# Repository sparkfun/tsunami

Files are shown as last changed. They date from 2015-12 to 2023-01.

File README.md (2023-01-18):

_Note: This repository is for the Tsunami Super WAV Trigger v1.1. For v1.2, check out the [Tsunami Super WAV Trigger (Qwiic) v1.2 GitHub repository](https://github.com/sparkfun/SparkFun_Tsunami_Super_WAV_Trigger_Qwiic)._

Tsunami Super WAV Trigger
========================================

Tsunami Super WAV Trigger (https://www.sparkfun.com/products/retired/13810)

[*Tsunami Super WAV Trigger (WIG-13810)*](https://www.sparkfun.com/products/retired/13810)

Tsunami is a polyphonic Wav file player with 4 stereo (or 8 mono) outputs.  Wav files can be triggered using the 16 onboard contacts, via MIDI, or using a serial connection to a PC or other microcontroller.

Repository Contents
-------------------

* **/Documentation** - Data sheets, additional product information
* **/Hardware** - Eagle design files (.brd, .sch)
* **/Production** - Production panel files (.brd)

Documentation
--------------
* **[Hookup Guide](https://learn.sparkfun.com/tutorials/tsunami-hookup-guide)** - Basic hookup guide for Tsunami v1.1.
* **[Official User Guide](https://cdn.sparkfun.com/assets/e/9/9/8/e/Tsunami_UserGuide_20230114.pdf)** - More detailed user guide, hosted by Robertsonics.
* **[Official Downloads Page](http://robertsonics.com/downloads/)** - Download supporting files, including firmware updates and the configuration utility.
* **[SparkFun Fritzing repo](https://github.com/sparkfun/Fritzing_Parts)** - Fritzing diagrams for SparkFun products.
* **[SparkFun 3D Model repo](https://github.com/sparkfun/3D_Models)** - 3D models of SparkFun products.

Product Versions
----------------
* [WIG-13810](https://www.sparkfun.com/products/13810) - First hardware revision.

Version History
---------------
* [Initial production Release](https://github.com/sparkfun/tsunami/commit/f42b14d72773535e83374cde73f2ca3f25164abb) - V11 hardware revision.

License Information
-------------------

The hardware design of Tsunami is _**open source**_!

Please review the LICENSE.md file for license information.

If you have any questions or concerns on licensing, please contact techsupport@sparkfun.com.

Distributed as-is; no warranty is given.

- Your friends at SparkFun.

Authors
----

Jamie Robertson @ Robertsonics & Byron Jacquot @ SparkFun Electronics

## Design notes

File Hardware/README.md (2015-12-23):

SparkFun <PRODUCT NAME> Design Files
=====================================

The .sch and .brd files hare are Eagle CAD schematic and PCB design files from SparkFun Electronics.
A freeware version of Eagle can be found [here](http://www.cadsoftusa.com/download-eagle/freeware/).

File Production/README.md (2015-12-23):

SparkFun <PRODUCT NAME> Production Files
=========================================

These are the production files SparkFun uses for printing PCBs.

License Information
-------------------
This product is open source! 

The hardware is released under [Creative Commons ShareAlike 4.0 International](https://creativecommons.org/licenses/by-sa/4.0/).

Please use, reuse, and modify these files as you see fit. Please maintain attribution to SparkFun Electronics and release anything derivative under the same license.

Distributed as-is; no warranty is given.

- Your friends at SparkFun.

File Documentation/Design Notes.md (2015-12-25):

###Tapestry Design Notes:

The initial Tapestry audio engine board is designed to be used for development purposes, and provides the basic components
of a high performance audio DSP/Playback engine, including an Atmel SAM S70 Arm Cortex M7 CPU, a microSD socket connected
via SDIO, a high-speed USB port and an AKM multi-channel audio codec providing 4 channels of input and 6 channels of output.
It also includes 10-pin, 0.05" pitch SWD/JTAG connector for use with the Atmel SAM ICE debugger during firmware development.

The design assumes that most user interface controls and connnectors, audio buffering and connectors, as well as any specific
external power connection and regulation will be contained on a second application specific "UI" board. In this way, the audio
engine can be repurposed for different end-user applications and requirements.

**Power**

Vin is assumed to be 5V. The design intent is that 5V can be supplied either through the UI header or from the USB
connection, or both. If both are plugged in, the external 5V Vin will be favored. If a wider input range using a barrel or
other type of power connector is required, the connector itself and any additional regulation can located on the UI board.

**microSD Socket**

The microSD card interfaces to the CPU using the 4-bit wide SDIO interface rather than SPI. The Atmel SAM 70 CPU is able
to recognize high speed cards and run the SDIO clock at 50Mhz, making the layout of the card and routing of the SDIO traces
somewhat critical. SDIO signals and traces should be treated as high frequency.

**Codec**

The codec interfaces to the CPU using the SAM S70 SAI resource in TDM mode for audio, and I2C for control. The design allows
for up to 4 audio input channels and 6 audio output channels.  A dual-row, 20-pin connector JP4 provides the ac coupled audio
input and output connections to and from the codec. Any additional audio signal conditioning / buffering, as well as the
desired audio connectors are assumed to be on the UI board.

**User and Control Interface**

All user interface/control signals, including Vin, are via a dual-row 26 pin header JP3. There are 16 GPIO, 8 of which
can also be configured as analog inputs or outputs. The intent is that alternate firmware versions can use these lines to
interface to trigger or gate inputs, and/or user interface controls such as analog pots, encoders, LEDs, etc. There are also
2 UARTs (Tx and Rx), one of which will be dedicated for MIDI (with the MIDI opto-isolator, related components and connectors
being located on the UI board.)

**Test Points**

Test points are provided for the TDM signals between the SAM S70 and codec. Test points are also provide for a subset of
the SDIO signals to facilitate timing SD card access. A single general purpose test point is also provided for use by the
firmware.

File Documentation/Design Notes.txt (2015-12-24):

Tapestry Design Notes:

The initial Tapestry audio engine board is designed to be used for development purposes, and provides the basic components
of a high performance audio DSP/Playback engine, inlcuding the Arm Cortex M7 CPU, a microSD socket connected via SDIO, a
high-speed USB port and a multi-channel audio codec providing 4 channels of input and 6 channels of output. It also includes
10-pin, 0.05 pitch SWD/JTAG connector for use with the Atmel SAM ICE debugger during firmware development.

The design assumes that most user interface controls and connnectors, audio buffering and connectors, as well as any specific
external power connection and regulation will be contained on a second application specific "UI" board. In this way, the audio
engine can be repurposed for different end-user applications and requirements.

Power

Vin is assumed to be 5V. The design intent is that 5V can be supplied either through the UI header or from the USB
connection, or both. If both are plugged in, the external 5V Vin will be favored. If a wider input range using a barrel
connector is required, the connector and additional regulation can located on the UI board.

microSD Socket

The microSD card interfaces to the CPU using the 4-bit wide SDIO interface rather than SPI. The Atmel SAM 70 CPU is able
to recognize high speed cards and run the SDIO clock at 50Mhz, making the layout of the card and routing of the SDIO traces
somewhat more critical. SDIO signals and traces should be considered high frequency.

Codec

The codec interfaces to the CPU using the SAM S70 SAI resource in TDM mode. The design allows for up to 4 audio input
channels and 6 audio output channels.  A dual-row 20-pin connector JP4 provides the ac coupled audio input and output
connections to and from the codec. Any additional audio signal conditioning / buffering as well as the desired audio
connectors is assumed to be on the UI board.

User and Control Interface

All user interface/control signals, including Vin, are via a dual-row 26 pin header JP3. There are 16 GPIO, 8 of which
can also be configured as analog inputs or outputs. The intent is that alternate firmware versions can use these lines to
interface to trigger or gate inputs, user interface controls such as analog pots, encoders, LEDs, etc. There are also 2 UARTs
(Tx and Rx), one of which will be used for MIDI (with the MIDI opto and connectors being located on the UI board.)

Test Points

Test points are provided for the TDM signals between the SAM S70 and codec. Test points are also provide for a subset of
the SDIO signals to facilitate timing SD card access. A single general purpose test point is also provided for use by the
firmware.

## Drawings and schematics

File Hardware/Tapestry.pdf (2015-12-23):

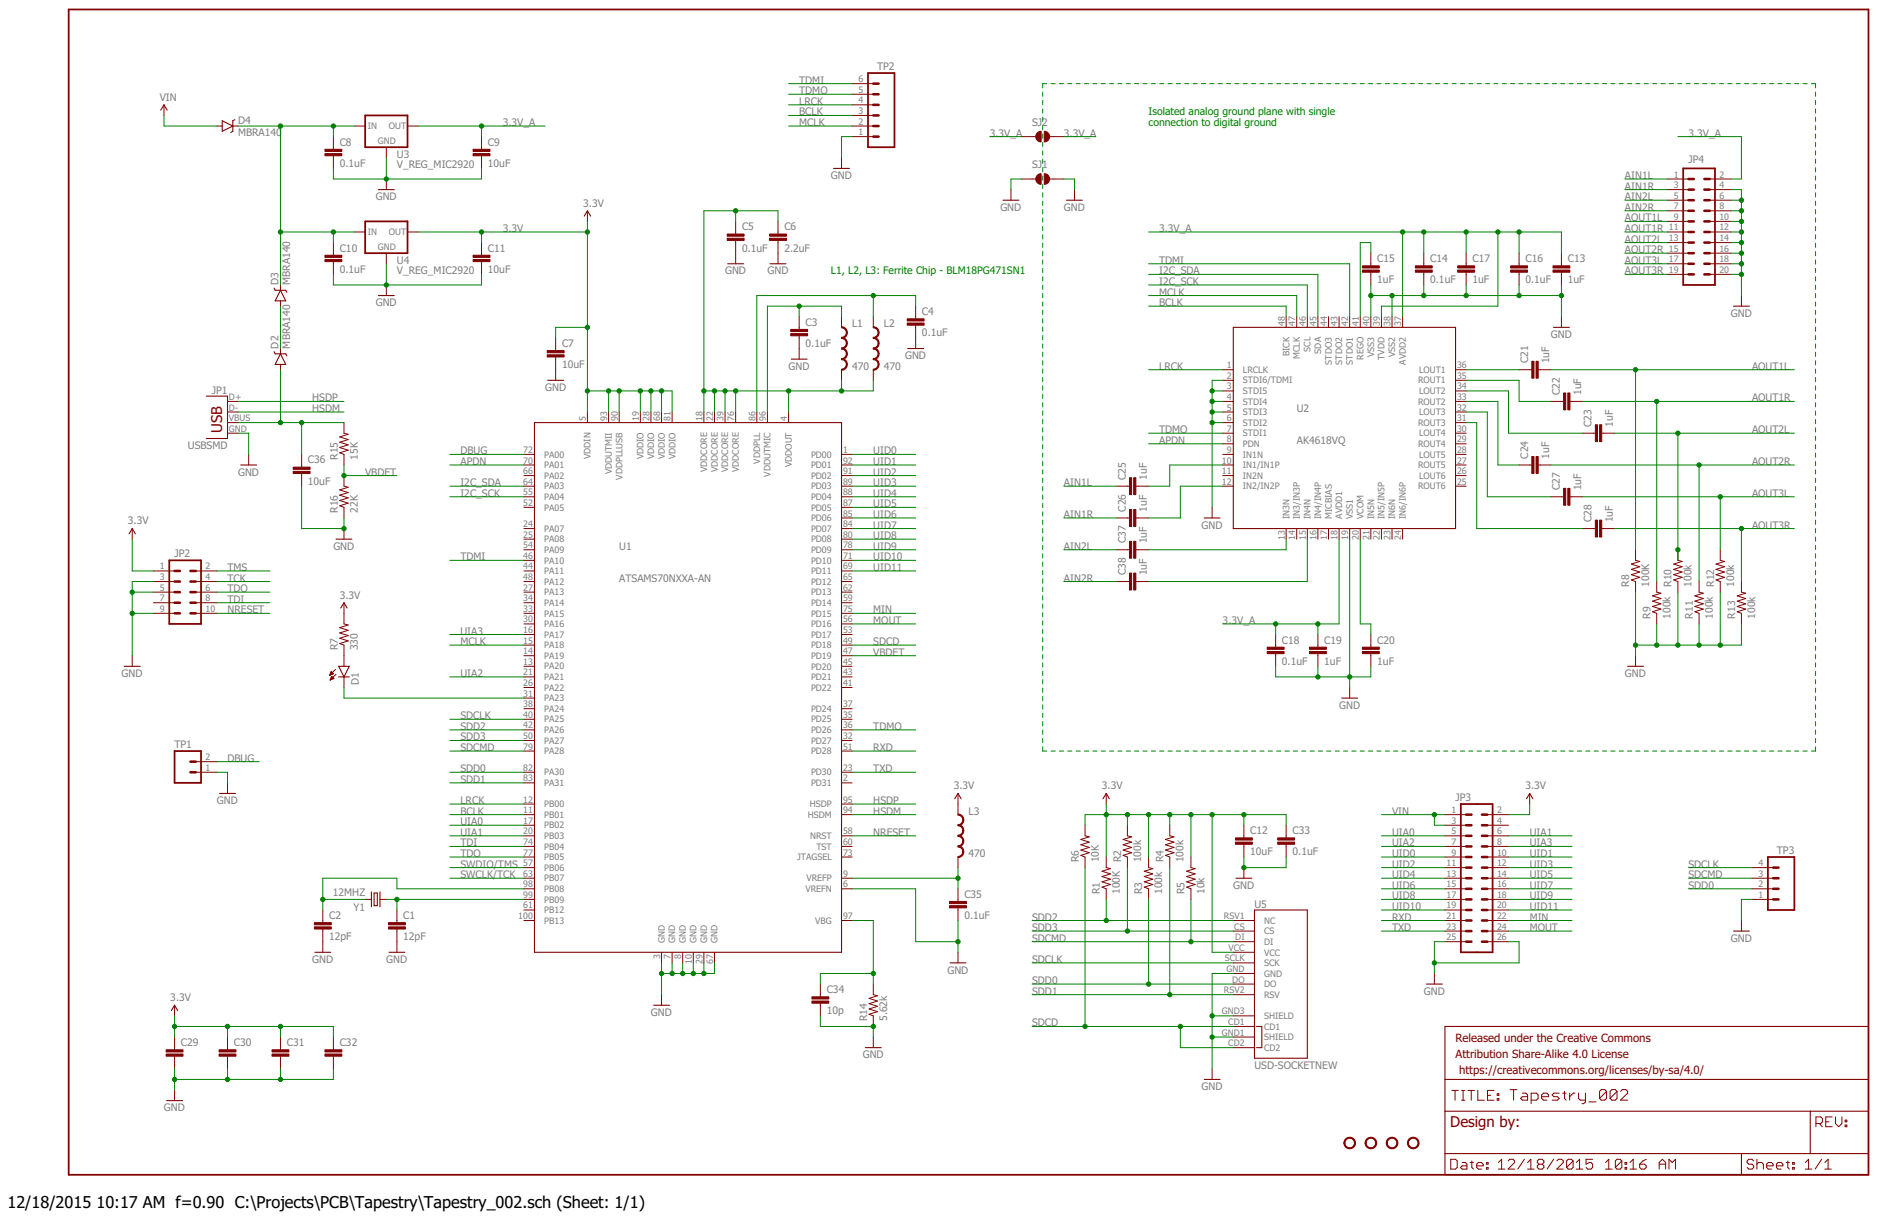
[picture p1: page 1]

Isolated analog ground plane with single
connection to digital ground

Released under the Creative Commons Attribution Share-Alike 4.0 License https://creativecommons.org/licenses/by-sa/4.0/

12/18/2015 10:17 AM f=0.90 C:\Projects\PCB\Tapestry\Tapestry_002.sch (Sheet: 1/1)

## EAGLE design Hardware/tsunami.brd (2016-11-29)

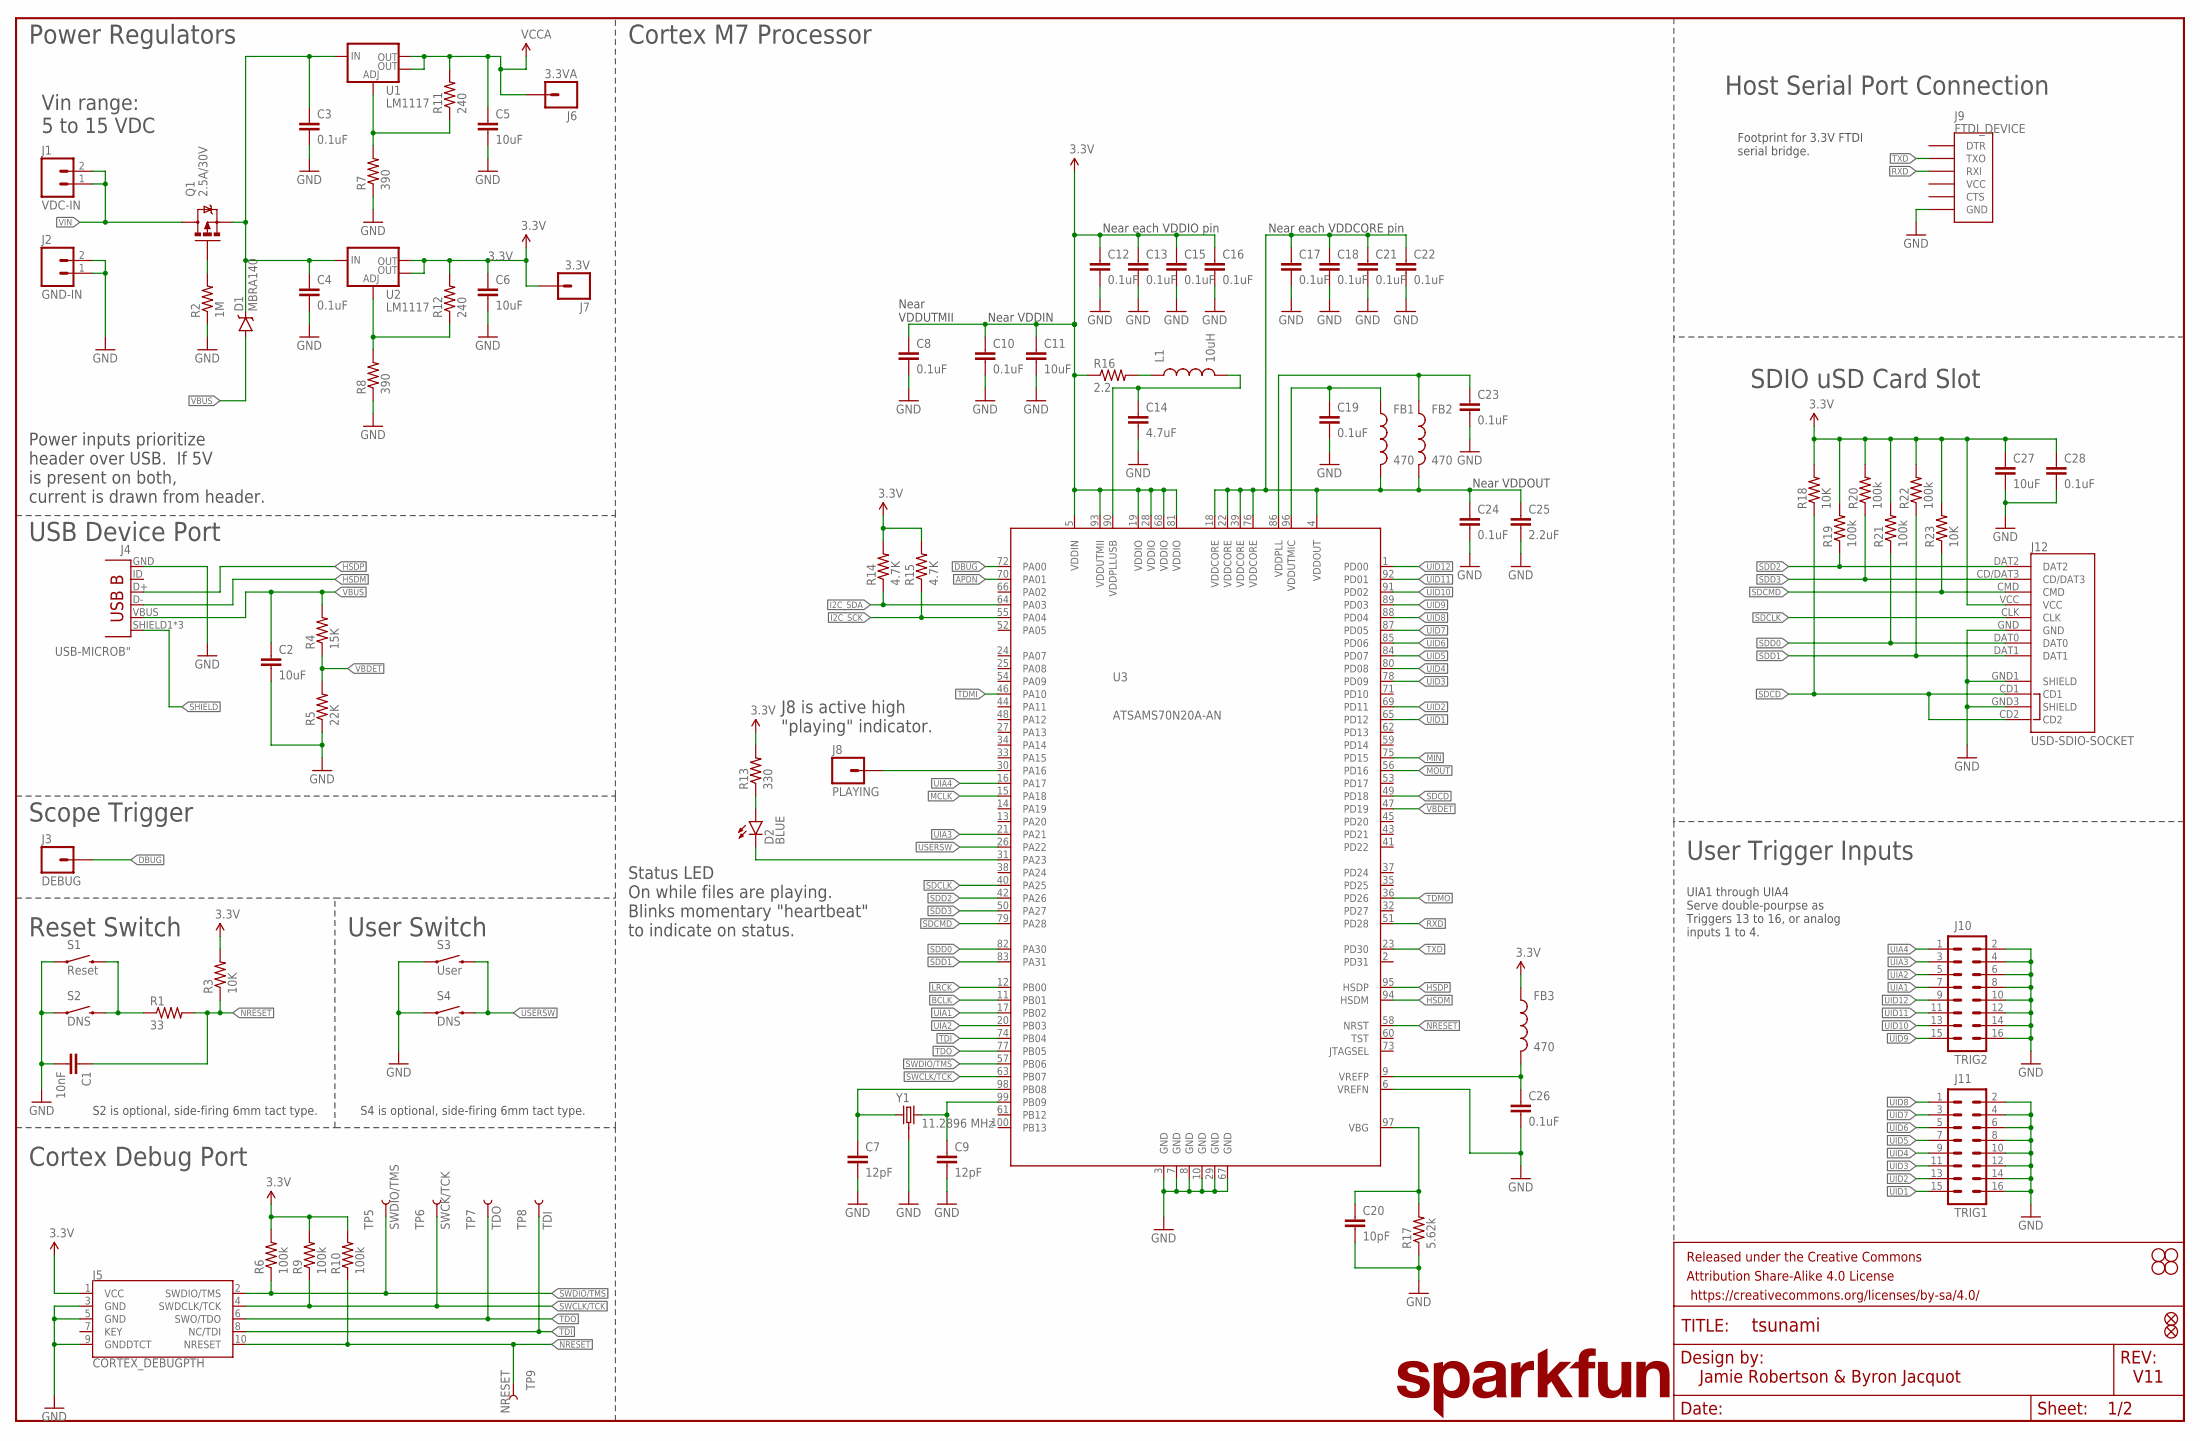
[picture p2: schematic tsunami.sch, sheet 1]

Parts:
C1: 10nF; 0603-CAP
C2, C5, C6, C11, C27: 10uF; 0603-CAP
C3, C4, C8, C10, C12, C13, C15, C16, C17, C18, C19, C21, C22, C23, C24, C26, C28: 0.1uF; 0603-CAP
C7, C9: 12pF; 0603-CAP
C14: 4.7uF; 0603-CAP
C20: 10pF; 0603-CAP
C25: 2.2uF; 0603-CAP
D1: MBRA140; SMA-DIODE
D2: BLUE; LED-0603
FB1, FB2, FB3: 470; 0603
FD1, FD2: FIDUCIALUFIDUCIAL; MICRO-FIDUCIAL
FRAME1: FRAME-LEDGER; CREATIVE_COMMONS
H1, H2, H3, H4: STAND-OFF
J1: VDC-IN; 1X02
J2: GND-IN; 1X02
J3: DEBUG; 1X01_NO_SILK
J4: USB-MICROB"; USB-B-MICRO-SMD_V03
J5: CORTEX_DEBUGPTH; 2X5-PTH-1.27MM
J6: 3.3VA; 1X01_NO_SILK
J7: 3.3V; 1X01_NO_SILK
J8: PLAYING; 1X01_NO_SILK
J9: FTDI_DEVICE; FTDI_DEVICE_SIDE
J10: TRIG2; 2X8
J11: TRIG1; 2X8
J12: USD-SDIO-SOCKET; MICRO-SD-SOCKET-SDIO
L1: 10uH; 0805
LOGO1: SFE_LOGO_NAME.2_INCH; SFE_LOGO_NAME_.2
Q1: 2.5A/30V; SOT23-3
R1: 33; 0603-RES
R2: 1M; 0603-RES
R3, R18, R23: 10K; 0603-RES
R4: 15K; 0603-RES
R5: 22K; 0603-RES
R6, R9, R10, R19, R20, R21, R22: 100k; 0603-RES
R7, R8: 390; 0603-RES
R11, R12: 240; 0603-RES
R13: 330; 0603-RES
R14, R15: 4.7K; 0603-RES
R16: 2.2; 0603-RES
R17: 5.62k; 0603-RES
S1: Reset; TACTILE-SWITCH-SMD
S2, S4: DNS; TACTILE-PTH-SIDEEZ
S3: User; TACTILE-SWITCH-SMD
TP5: SWDIO/TMS; TP_15TH
TP6: SWCK/TCK; TP_15TH
TP7: TDO; TP_15TH
TP8: TDI; TP_15TH
TP9: NRESET; TP_15TH
U1, U2: LM1117; SOT223
U3: ATSAMS70N20A-AN; LQFP100
Y1: 11.2896 MHz; CRYSTAL-OSC-SMD-5X3

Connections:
3.3V: C6.1, C8.1, C10.1, C11.1, C12.1, C13.1, C15.1, C16.1, C27.1, C28.1, FB3.1, J5.1 (VCC), J7.1, J12.VCC, R3.2, R6.2, R9.2, R10.2, R12.2, R13.2, R14.2, R15.2, R16.1, R18.2, R19.2, R20.2, R21.2, R22.2, R23.2, U2.2 (OUT), U2.4 (OUT), U3.5 (VDDIN), U3.19 (VDDIO), U3.28 (VDDIO), U3.68 (VDDIO), U3.81 (VDDIO), U3.93 (VDDUTMII); also elsewhere on the board
APDN: U3.70 (PA01); also elsewhere on the board
BCLK: U3.11 (PB01); also elsewhere on the board
DBUG: J3.1, U3.72 (PA00)
GND: C1.2, C2.2, C3.2, C4.2, C5.2, C6.2, C7.2, C8.2, C9.2, C10.2, C11.2, C12.2, C13.2, C14.2, C15.2, C16.2, C17.2, C18.2, C19.2, C20.2, C21.2, C22.2, C23.2, C24.2, C25.2, C26.2, C27.2, C28.2, J2.1, J2.2, J4.GND, J5.3 (GND), J5.5 (GND), J5.9 (GNDDTCT), J9.P$6 (GND), J10.2, J10.4, J10.6, J10.8, J10.10, J10.12, J10.14, J10.16, J11.2, J11.4, J11.6, J11.8, J11.10, J11.12, J11.14, J11.16, J12.GND, J12.GND1 (SHIELD), J12.GND3 (SHIELD), R2.1, R5.1, R7.1, R8.1, R17.1, S1.1, S2.1, S3.1, S4.1, U3.3 (GND), U3.6 (VREFN), U3.7 (GND), U3.8 (GND), U3.10 (GND), U3.29 (GND), U3.67 (GND), Y1.2 (3), Y1.4 (3); also elsewhere on the board
HSDM: J4.D-, U3.94 (HSDM)
HSDP: J4.D+, U3.95 (HSDP)
I2C_SCK: R15.1, U3.55 (PA04); also elsewhere on the board
I2C_SDA: R14.1, U3.64 (PA03); also elsewhere on the board
LRCK: U3.12 (PB00); also elsewhere on the board
MCLK: U3.15 (PA18); also elsewhere on the board
MIN: U3.75 (PD15); also elsewhere on the board
MOUT: U3.56 (PD16); also elsewhere on the board
unnamed: C7.1, U3.98 (PB08), Y1.1
unnamed: C9.1, U3.99 (PB09), Y1.3 (2)
unnamed: C19.1, FB1.1, U3.96 (VDDUTMIC)
unnamed: C14.1, L1.2, U3.90 (VDDPLLUSB)
unnamed: C23.1, FB2.1, U3.86 (VDDPLL)
unnamed: J8.1, U3.30 (PA16)
unnamed: D2.C, U3.31 (PA23)
unnamed: D2.A, R13.1
unnamed: C20.1, R17.2, U3.97 (VBG)
unnamed: C26.1, FB3.2, U3.9 (VREFP)
unnamed: L1.1, R16.2
unnamed: R7.2, R11.1, U1.1 (ADJ)
unnamed: R1.1, S1.3 (2), S2.2
unnamed: R8.2, R12.1, U2.1 (ADJ)
unnamed: Q1.1 (G), R2.2
NRESET: C1.1, J5.10 (NRESET), R1.2, R3.1, R10.1, TP9.P$1, U3.58 (NRST)
REGINPUTS: C3.1, C4.1, D1.C, Q1.2 (S), U1.3 (IN), U2.3 (IN)
RXD: J9.P$3 (RXI), U3.51 (PD28)
SDCD: J12.CD1, J12.CD2, R18.1, U3.49 (PD18)
SDCLK: J12.CLK, U3.40 (PA25)
SDCMD: J12.CMD, R23.1, U3.79 (PA28)
SDD0: J12.DAT0, R21.1, U3.82 (PA30)
SDD1: J12.DAT1, R22.1, U3.83 (PA31)
SDD2: J12.DAT2, R19.1, U3.42 (PA26)
SDD3: J12.CD/DAT3, R20.1, U3.50 (PA27)
SHIELD: J4.SHIELD1 (SHIELD), J4.SHIELD2 (SHIELD), J4.SHIELD3 (SHIELD)
SWCLK/TCK: J5.4 (SWDCLK/TCK), R9.1, TP6.P$1, U3.63 (PB07)
SWDIO/TMS: J5.2 (SWDIO/TMS), R6.1, TP5.P$1, U3.57 (PB06)
TDI: J5.8 (NC/TDI), TP8.P$1, U3.74 (PB04)
TDMI: U3.46 (PA10); also elsewhere on the board
TDMO: U3.36 (PD26); also elsewhere on the board
TDO: J5.6 (SWO/TDO), TP7.P$1, U3.77 (PB05)
TXD: J9.P$2 (TXO), U3.23 (PD30)
UIA1: J10.7, U3.17 (PB02)
UIA2: J10.5, U3.20 (PB03)
UIA3: J10.3, U3.21 (PA21)
UIA4: J10.1, U3.16 (PA17)
UID1: J11.15, U3.65 (PD12)
UID2: J11.13, U3.69 (PD11)
UID3: J11.11, U3.78 (PD09)
UID4: J11.9, U3.80 (PD08)
UID5: J11.7, U3.84 (PD07)
UID6: J11.5, U3.85 (PD06)
UID7: J11.3, U3.87 (PD05)
UID8: J11.1, U3.88 (PD04)
UID9: J10.15, U3.89 (PD03)
UID10: J10.13, U3.91 (PD02)
UID11: J10.11, U3.92 (PD01)
UID12: J10.9, U3.1 (PD00)
USERSW: S3.3 (2), S4.2, U3.26 (PA22)
VBDET: R4.1, R5.2, U3.47 (PD19)
VBUS: C2.1, D1.A, J4.VBUS, R4.2
VCCA: C5.1, J6.1, R11.2, U1.2 (OUT), U1.4 (OUT); also elsewhere on the board
VDDOUT: C17.1, C18.1, C21.1, C22.1, C24.1, C25.1, FB1.2, FB2.2, U3.4 (VDDOUT), U3.18 (VDDCORE), U3.22 (VDDCORE), U3.39 (VDDCORE), U3.76 (VDDCORE)
VIN: J1.1, J1.2, Q1.3 (D)

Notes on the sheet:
Jamie Robertson & Byron Jacquot
V11
Near each VDDCORE pin
Near each VDDIO pin
Near VDDUTMII
Near VDDIN
Near VDDOUT
Power Regulators
USB Device Port
Scope Trigger
Cortex Debug Port
Cortex M7 Processor
SDIO uSD Card Slot
User Trigger Inputs
Reset Switch
S2 is optional, side-firing 6mm tact type.
Vin range: 5 to 15 VDC
Status LED On while files are playing. Blinks momentary "heartbeat" to indicate on status.
Power inputs prioritize header over USB. If 5V is present on both, current is drawn from header.
UIA1 through UIA4 Serve double-pourpse as Triggers 13 to 16, or analog inputs 1 to 4.
Host Serial Port Connection
Footprint for 3.3V FTDI serial bridge.
User Switch
J8 is active high "playing" indicator.
S4 is optional, side-firing 6mm tact type.

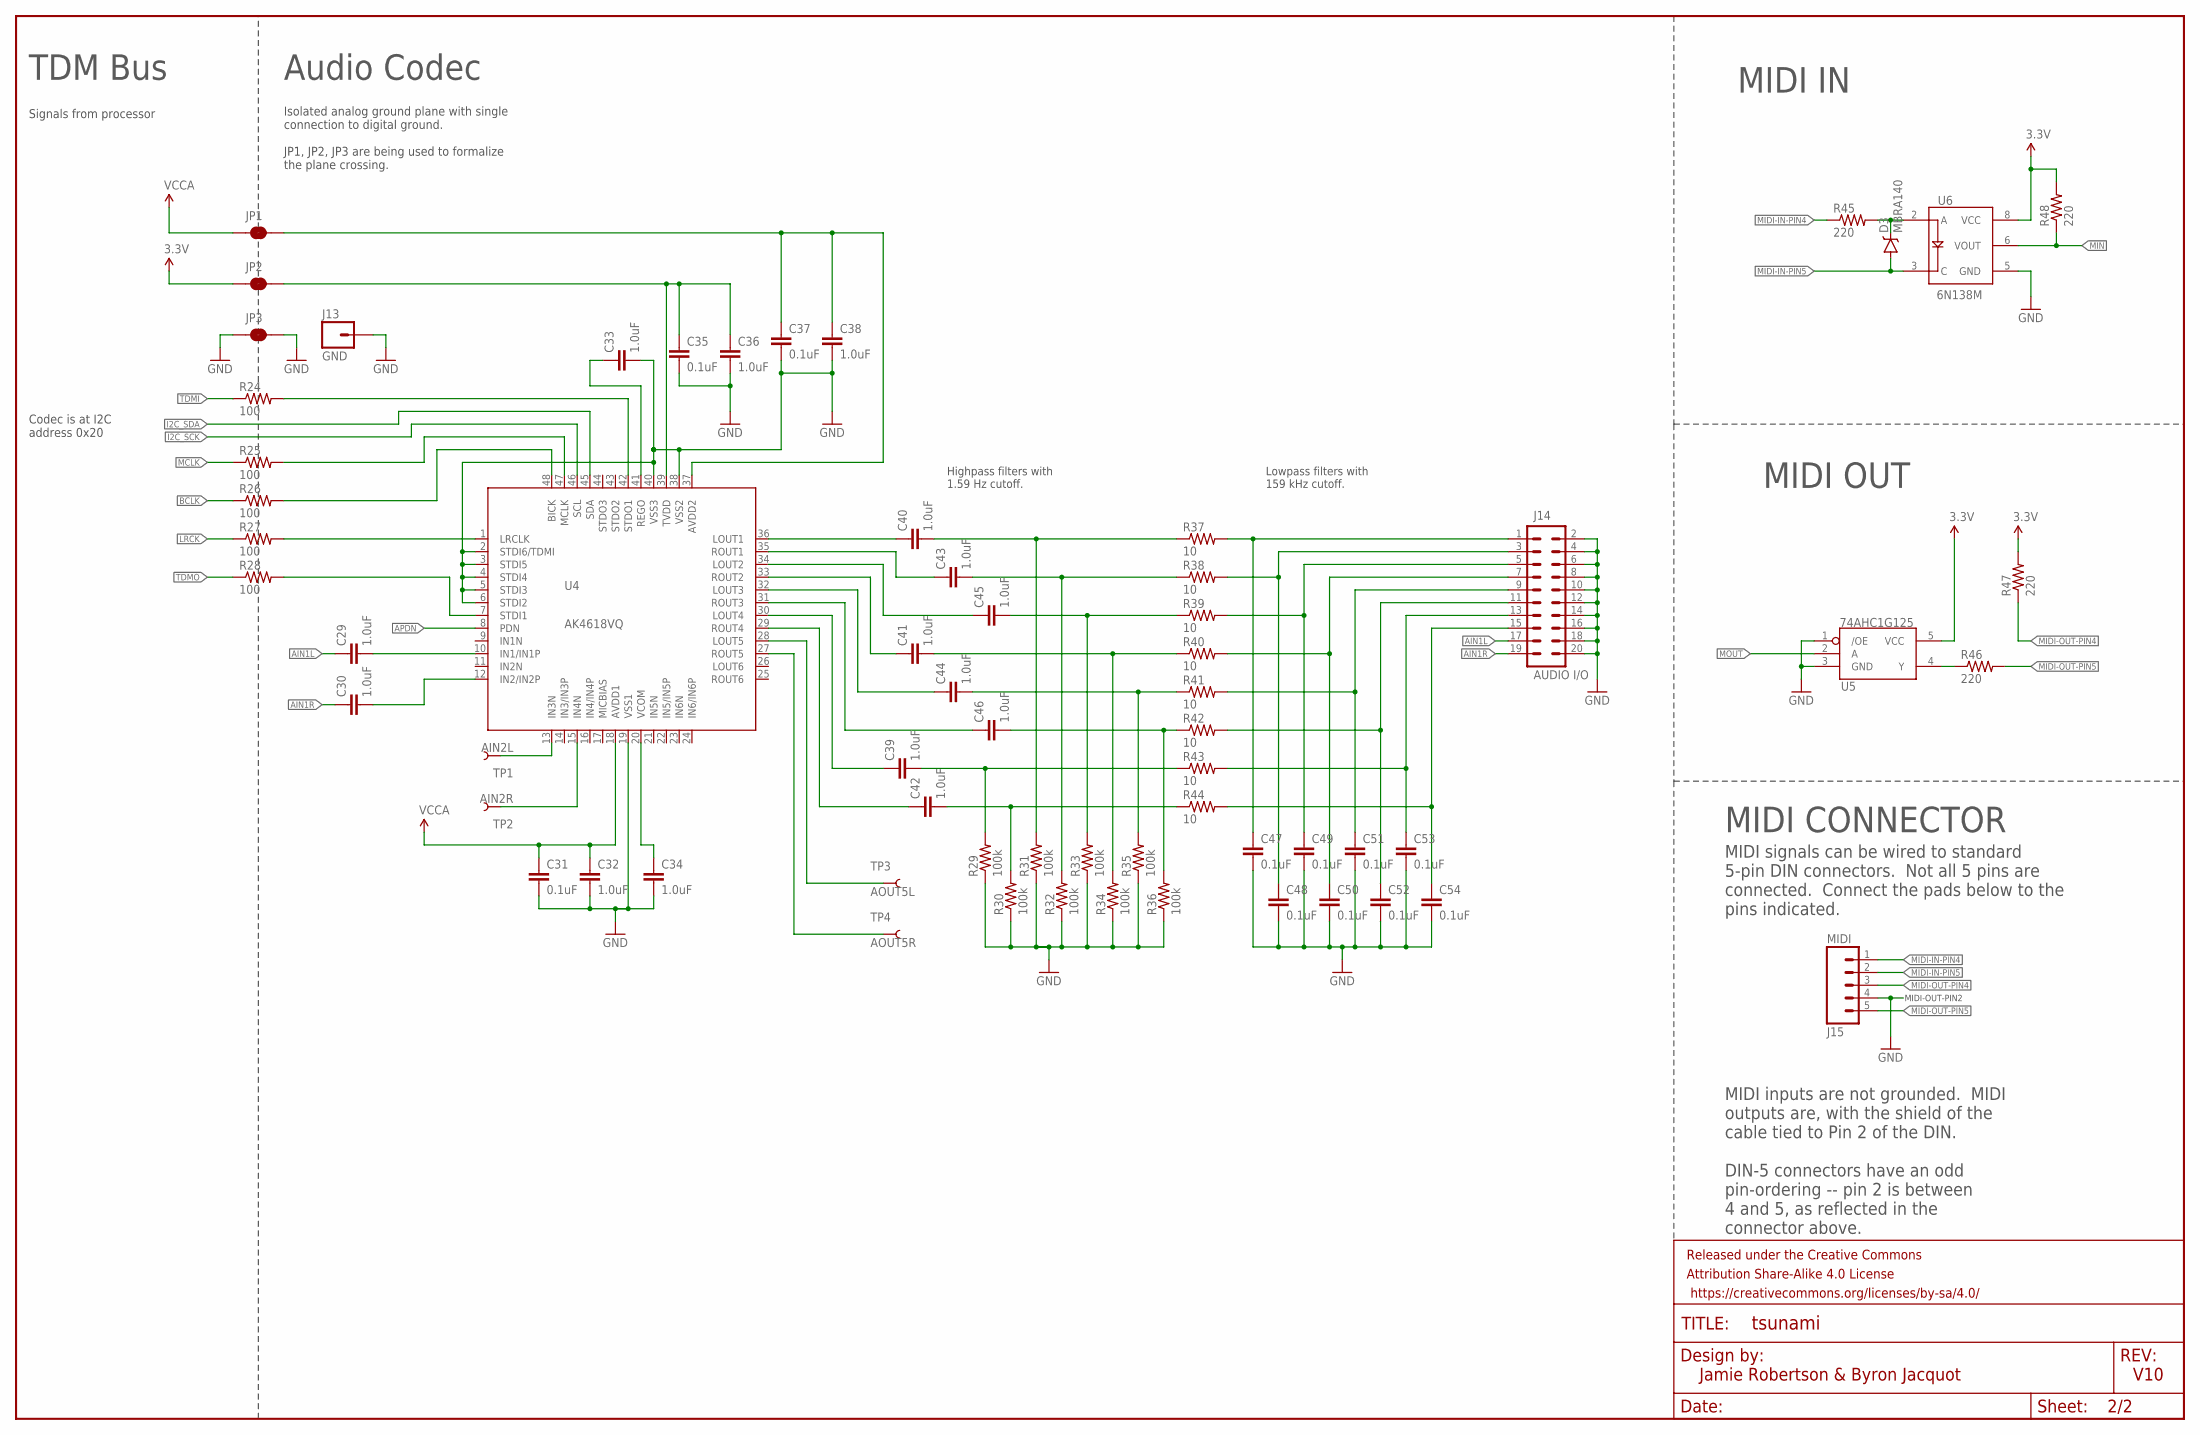
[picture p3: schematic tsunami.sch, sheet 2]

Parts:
C29, C30, C32, C33, C34, C36, C38, C39, C40, C41, C42, C43, C44, C45, C46: 1.0uF; 0603-CAP
C31, C35, C37, C47, C48, C49, C50, C51, C52, C53, C54: 0.1uF; 0603-CAP
D3: MBRA140; SMA-DIODE
FRAME2: FRAME-LEDGER; CREATIVE_COMMONS
J13: GND; 1X01_NO_SILK
J14: AUDIO I/O; 2X10
J15: MIDI; 1X05_NO_SILK
JP1, JP2, JP3: JUMPER-PAD-2-NC_BY_TRACENO_SILK; PAD-JUMPER-2-NC_BY_TRACE_NO_SILK
R24, R25, R26, R27, R28: 100; 0603-RES
R29, R30, R31, R32, R33, R34, R35, R36: 100k; 0603-RES
R37, R38, R39, R40, R41, R42, R43, R44: 10; 0603-RES
R45, R46, R47, R48: 220; 0603-RES
TP1: AIN2L; TP_15TH
TP2: AIN2R; TP_15TH
TP3: AOUT5L; TP_15TH
TP4: AOUT5R; TP_15TH
U4: AK4618VQ; LQFP-48
U5: 74AHC1G125; SOT23-5
U6: 6N138M; 8-SMD

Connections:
3.3V: C35.1, C36.1, JP2.1, JP2.2, R47.2, R48.2, U4.39 (TVDD), U5.5 (VCC), U6.8 (VCC); also elsewhere on the board
56: D3.C, R45.2, U6.2 (A)
AIN1L: C29.1, J14.17
AIN1R: C30.1, J14.19
AIN2L: TP1.P$1, U4.13 (IN3N)
AIN2R: TP2.P$1, U4.15 (IN4N)
AOUT1L: C47.1, J14.1, R37.2
AOUT1R: C48.1, J14.3, R38.2
AOUT2L: C49.1, J14.5, R39.2
AOUT2R: C50.1, J14.7, R40.2
AOUT3L: C51.1, J14.9, R41.2
AOUT3R: C52.1, J14.11, R42.2
AOUT4L: C53.1, J14.13, R43.2
AOUT4R: C54.1, J14.15, R44.2
APDN: U4.8 (PDN); also elsewhere on the board
BCLK: R26.1; also elsewhere on the board
BCLK_C: R26.2, U4.48 (BICK)
GND: C31.2, C32.2, C33.2, C34.2, C35.2, C36.2, C37.2, C38.2, C47.2, C48.2, C49.2, C50.2, C51.2, C52.2, C53.2, C54.2, J13.1, J14.2, J14.4, J14.6, J14.8, J14.10, J14.12, J14.14, J14.16, J14.18, J14.20, J15.4, JP3.1, JP3.2, R29.1, R30.1, R31.1, R32.1, R33.1, R34.1, R35.1, R36.1, U4.2 (STDI6/TDMI), U4.3 (STDI5), U4.4 (STDI4), U4.5 (STDI3), U4.6 (STDI2), U4.19 (VSS1), U4.38 (VSS2), U4.40 (VSS3), U5.1 (/OE), U5.3 (GND), U6.5 (GND); also elsewhere on the board
I2C_SCK: U4.46 (SCL); also elsewhere on the board
I2C_SDA: U4.45 (SDA); also elsewhere on the board
LRCK: R27.1; also elsewhere on the board
LRCK_C: R27.2, U4.1 (LRCLK)
MCLK: R25.1; also elsewhere on the board
MCLK_C: R25.2, U4.47 (MCLK)
MIDI-IN-PIN4: J15.1, R45.1
MIDI-IN-PIN5: D3.A, J15.2, U6.3 (C)
MIDI-OUT-PIN4: J15.3, R47.1
MIDI-OUT-PIN5: J15.5, R46.2
MIN: R48.1, U6.6 (VOUT); also elsewhere on the board
MOUT: U5.2 (A); also elsewhere on the board
unnamed: C33.1, U4.41 (REGO)
unnamed: C34.1, U4.20 (VCOM)
unnamed: C40.1, U4.36 (LOUT1)
unnamed: C30.2, U4.12 (IN2/IN2P)
unnamed: C29.2, U4.10 (IN1/IN1P)
unnamed: C43.1, U4.35 (ROUT1)
unnamed: C45.1, U4.34 (LOUT2)
unnamed: C41.1, U4.33 (ROUT2)
unnamed: C44.1, U4.32 (LOUT3)
unnamed: C46.1, U4.31 (ROUT3)
unnamed: C40.2, R31.2, R37.1
unnamed: C42.2, R30.2, R44.1
unnamed: C39.2, R29.2, R43.1
unnamed: C46.2, R36.2, R42.1
unnamed: C39.1, U4.30 (LOUT4)
unnamed: C42.1, U4.29 (ROUT4)
unnamed: TP3.P$1, U4.28 (LOUT5)
unnamed: TP4.P$1, U4.27 (ROUT5)
unnamed: R46.1, U5.4 (Y)
unnamed: C44.2, R35.2, R41.1
unnamed: C41.2, R34.2, R40.1
unnamed: C43.2, R32.2, R38.1
unnamed: C45.2, R33.2, R39.1
TDMI: R24.1; also elsewhere on the board
TDMI_C: R24.2, U4.42 (STDO1)
TDMO: R28.1; also elsewhere on the board
TDMO_C: R28.2, U4.7 (STDI1)
VCCA: C31.1, C32.1, C37.1, C38.1, JP1.1, JP1.2, U4.18 (AVDD1), U4.37 (AVDD2); also elsewhere on the board

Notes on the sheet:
Isolated analog ground plane with single connection to digital ground. JP1, JP2, JP3 are being used to formalize the plane crossing.
Audio Codec
MIDI IN
MIDI OUT
Jamie Robertson & Byron Jacquot
V10
TDM Bus
Signals from processor
MIDI CONNECTOR
MIDI signals can be wired to standard 5-pin DIN connectors. Not all 5 pins are connected. Connect the pads below to the pins indicated.
MIDI-OUT-PIN2
Codec is at I2C address 0x20
MIDI inputs are not grounded. MIDI outputs are, with the shield of the cable tied to Pin 2 of the DIN. DIN-5 connectors have an odd pin-ordering -- pin 2 is between 4 and 5, as reflected in the connector above.
Highpass filters with 1.59 Hz cutoff.
Lowpass filters with 159 kHz cutoff.

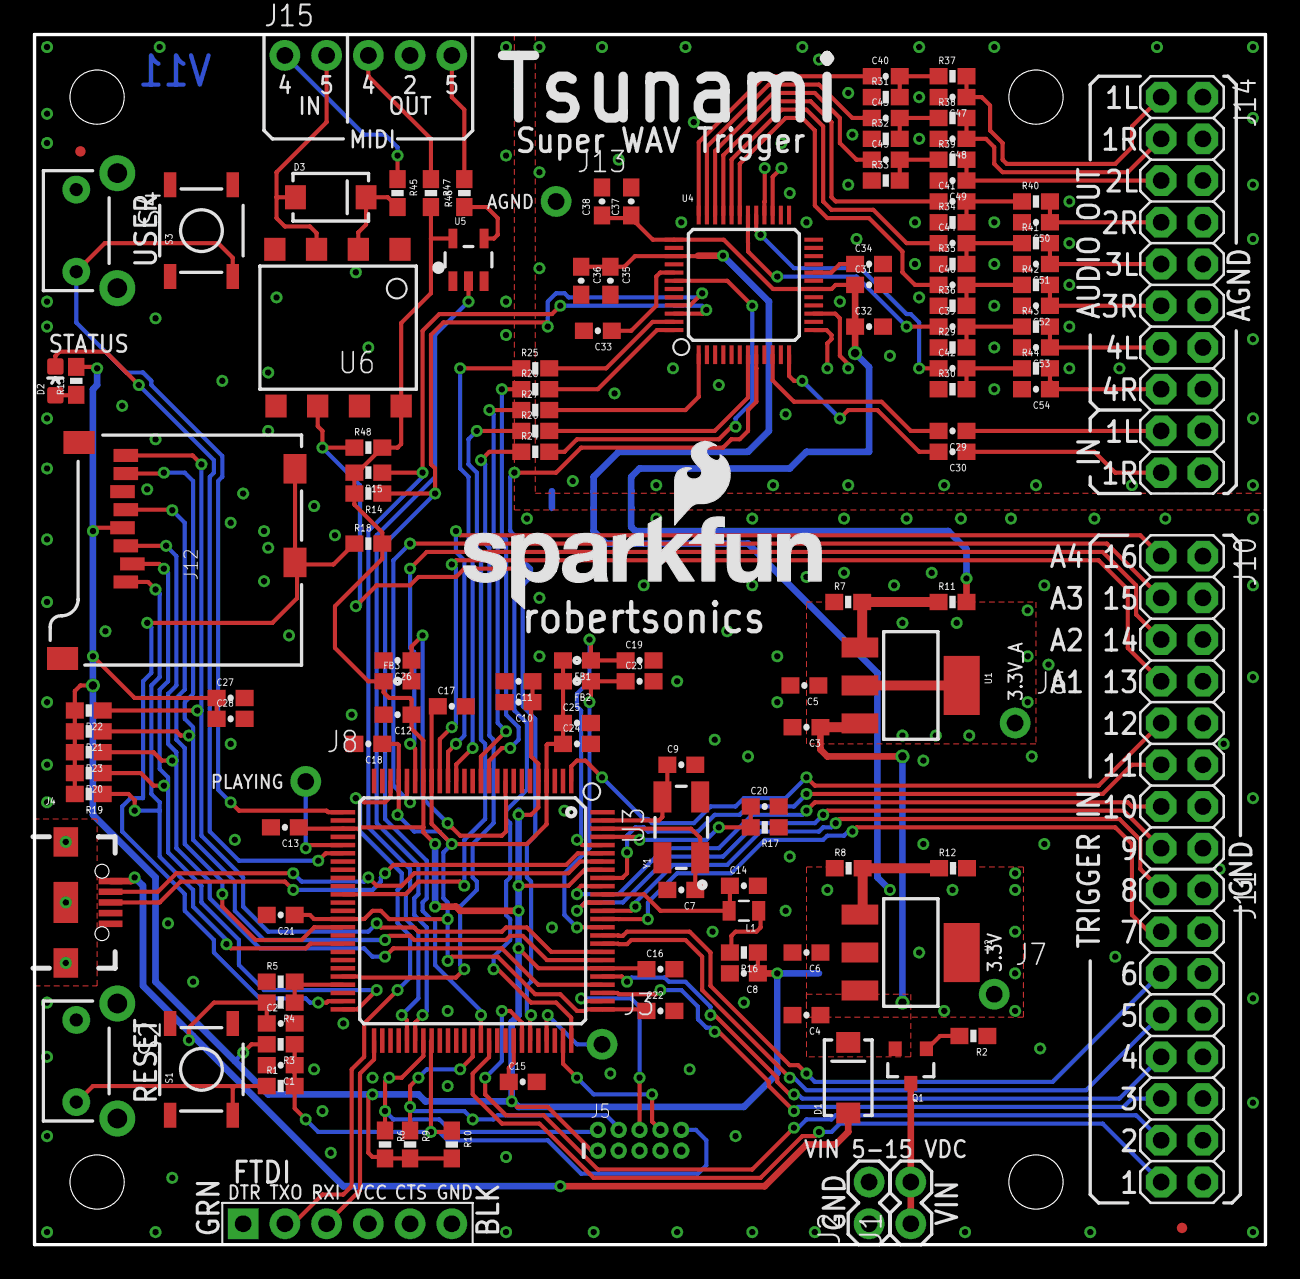
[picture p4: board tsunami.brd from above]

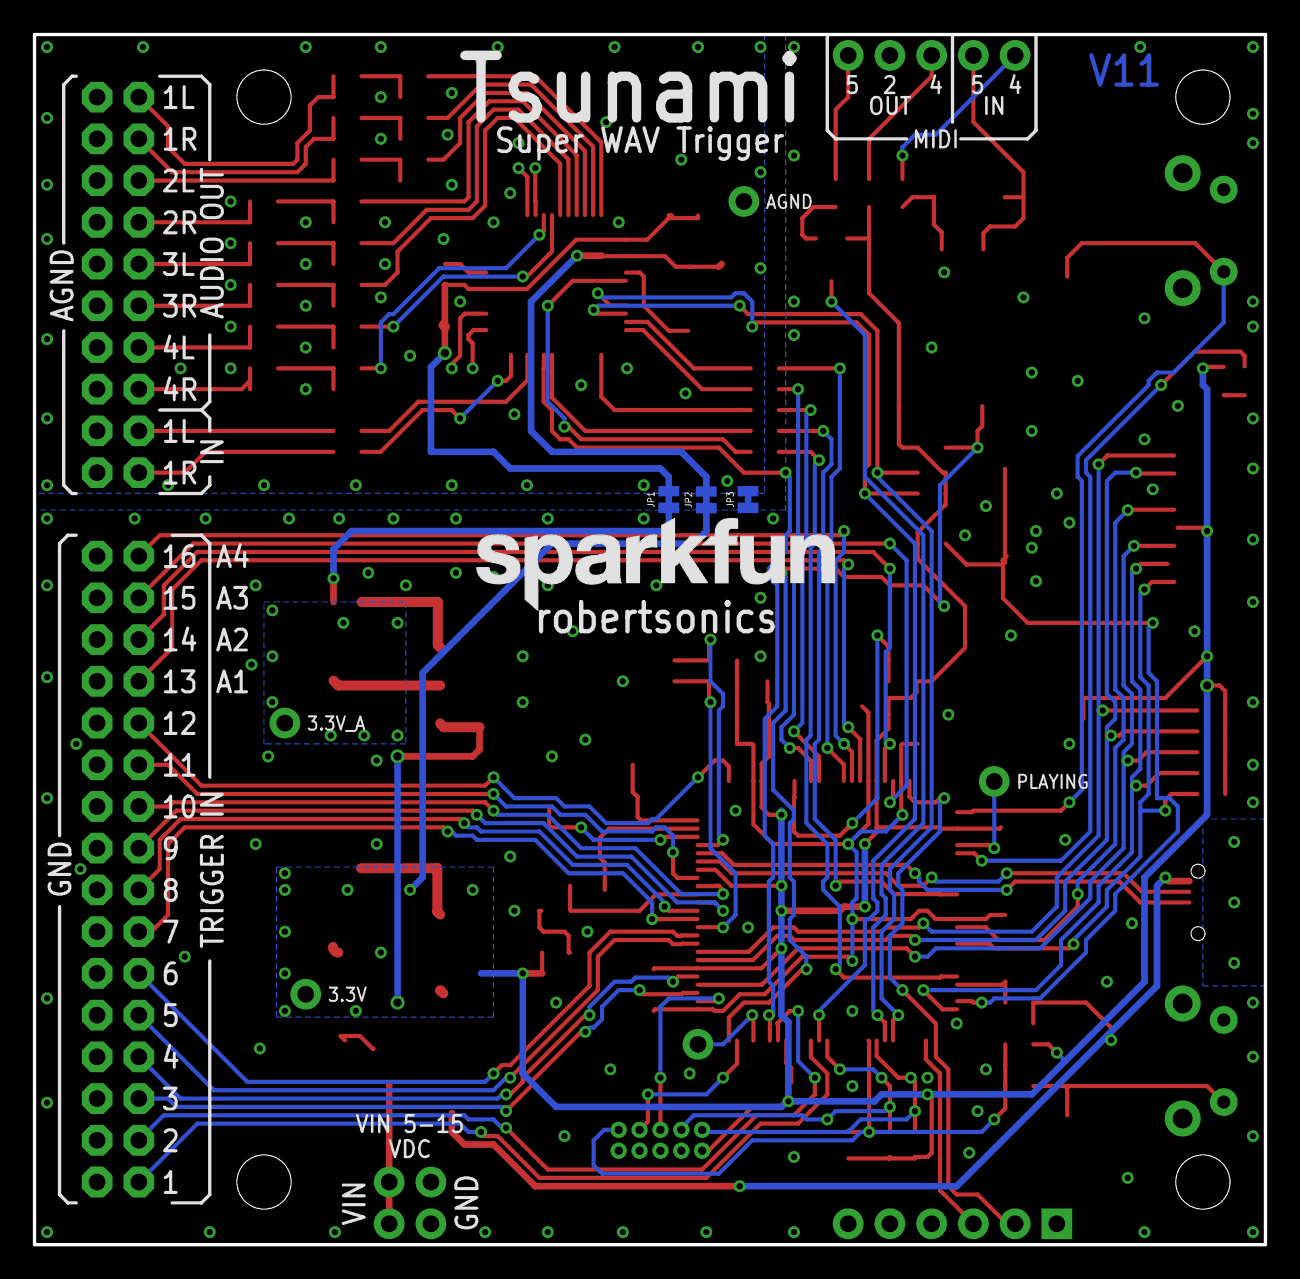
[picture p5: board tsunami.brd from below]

Board: 2 copper layers, 74.9 x 73.7 mm, 158 parts (4 on the bottom side), 113 nets.

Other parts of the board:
LOGO4: SFE_LOGO_NAME_FLAME.2_INCH; SFE_LOGO_NAME_FLAME_.2

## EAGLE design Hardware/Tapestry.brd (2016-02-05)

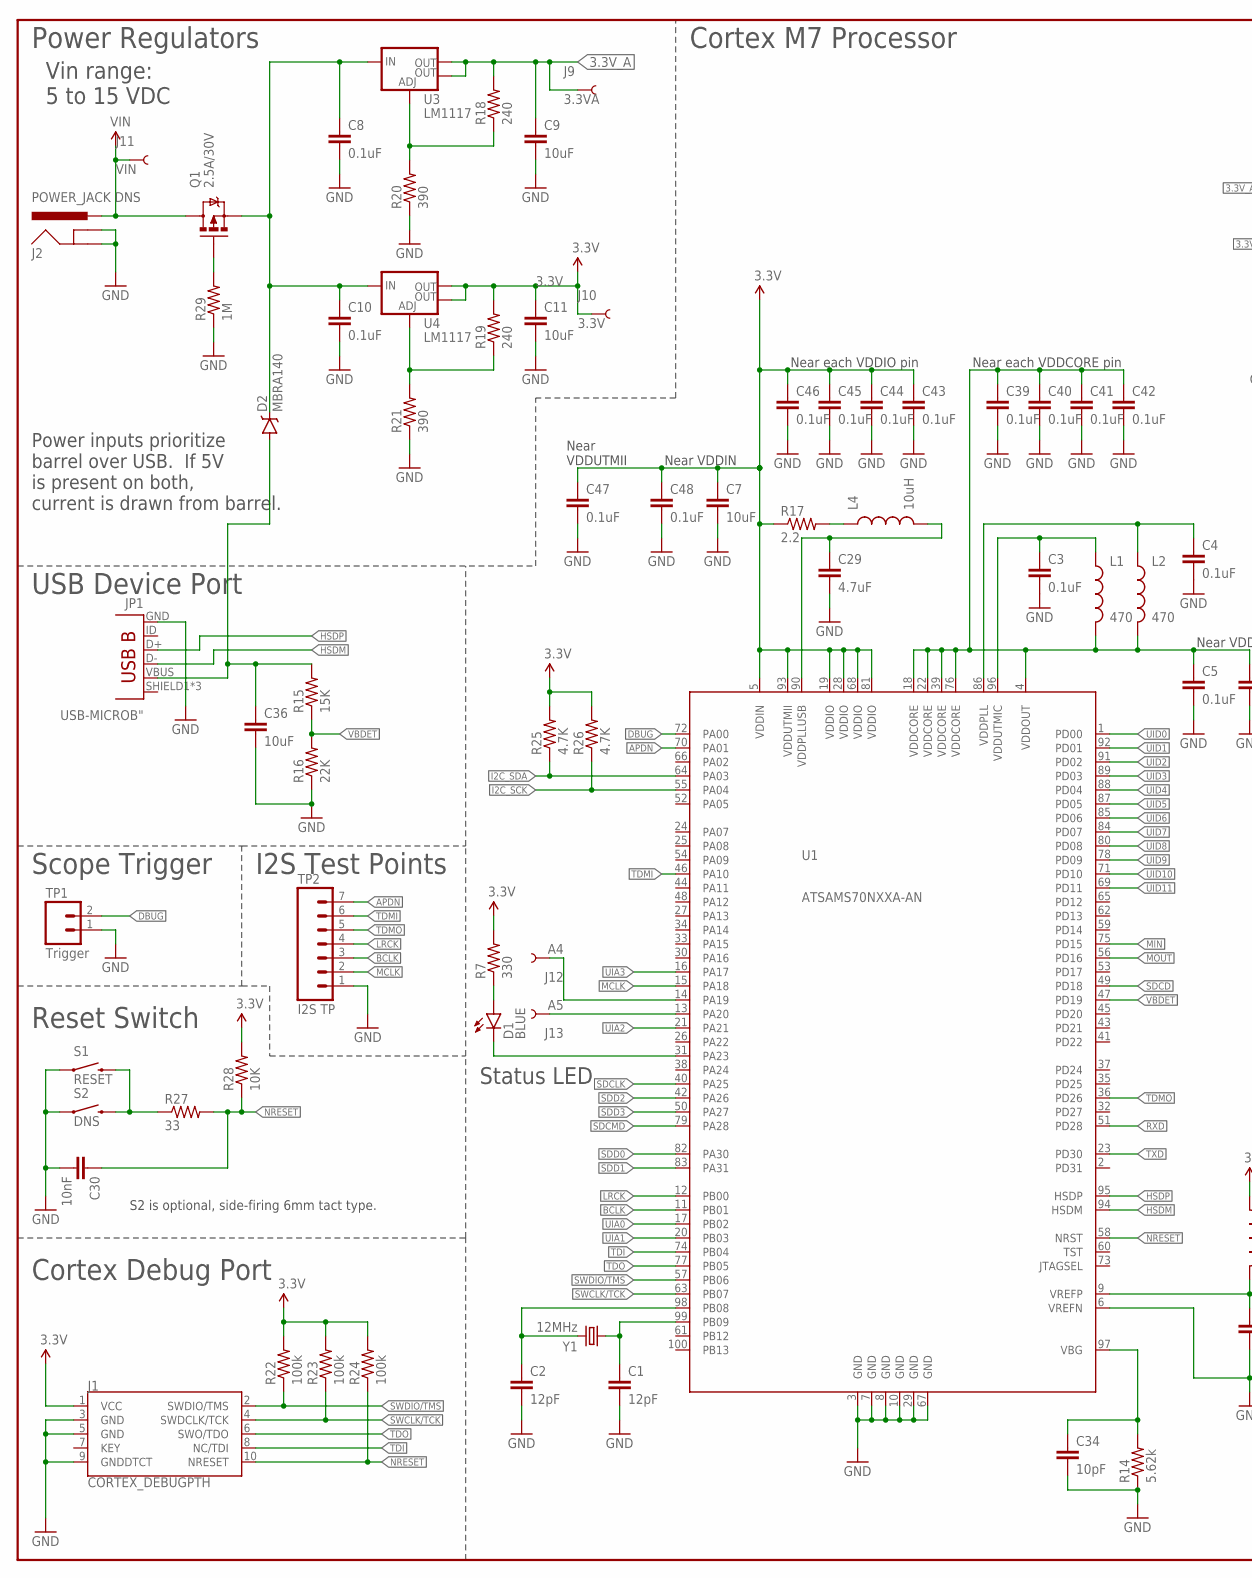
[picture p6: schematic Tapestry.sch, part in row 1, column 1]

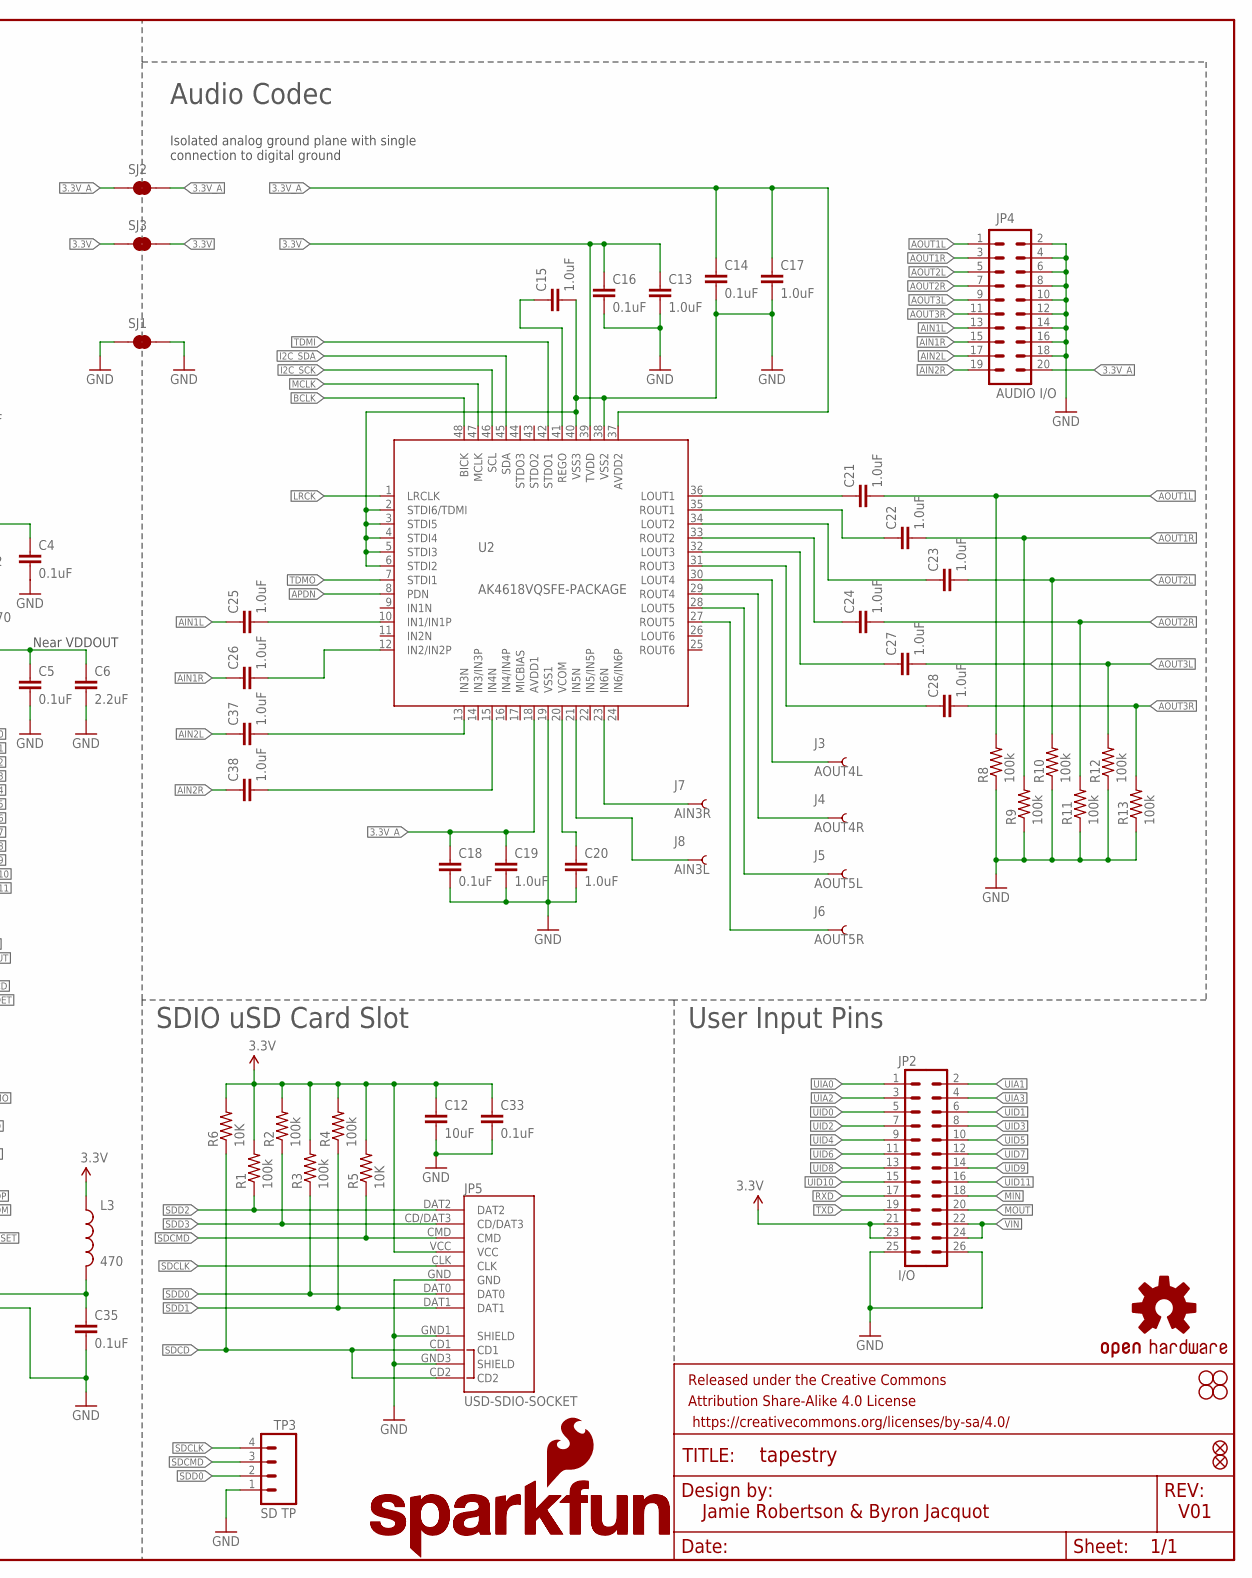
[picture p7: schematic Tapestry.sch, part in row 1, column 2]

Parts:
C1, C2: 12pF; 0603-CAP
C3, C4, C5, C8, C10, C14, C16, C18, C33, C35, C39, C40, C41, C42, C43, C44, C45, C46, C47, C48: 0.1uF; 0603-CAP
C6: 2.2uF; 0603-CAP
C7, C9, C11, C12, C36: 10uF; 0603-CAP
C13, C15, C17, C19, C20, C21, C22, C23, C24, C25, C26, C27, C28, C37, C38: 1.0uF; 0603-CAP
C29: 4.7uF; 0603-CAP
C30: 10nF; 0603-CAP
C34: 10pF; 0603-CAP
D1: BLUE; LED-0603
D2: MBRA140; SMA-DIODE
FD1, FD2: FIDUCIALUFIDUCIAL; MICRO-FIDUCIAL
FRAME1: FRAME-LEDGER; CREATIVE_COMMONS
J1: CORTEX_DEBUGPTH; 2X5-PTH-1.27MM
J2: POWER_JACK DNS; POWER_JACK_PTH_LOCK
J3: AOUT4L; TP_15TH
J4: AOUT4R; TP_15TH
J5: AOUT5L; TP_15TH
J6: AOUT5R; TP_15TH
J7: AIN3R; TP_15TH
J8: AIN3L; TP_15TH
J9: 3.3VA; TP_15TH
J10: 3.3V; TP_15TH
J11: VIN; TP_15TH
J12: A4; TP_15TH
J13: A5; TP_15TH
JP1: USB-MICROB"; USB-B-MICRO-SMD_V03
JP2: I/O; 2X13
JP4: AUDIO I/O; 2X10
JP5: USD-SDIO-SOCKET; MICRO-SD-SOCKET-SDIO
L1, L2, L3: 470; 0603
L4: 10uH; 0805
LOGO1: SFE_LOGO_NAME_FLAME.2_INCH; SFE_LOGO_NAME_FLAME_.2
LOGO2: OSHW-LOGOM; OSHW-LOGO-M
LOGO3: SFE_LOGO_NAME.2_INCH; SFE_LOGO_NAME_.2
Q1: 2.5A/30V; SOT23-3
R1, R2, R3, R4, R8, R9, R10, R11, R12, R13, R22, R23, R24: 100k; 0603-RES
R5, R6, R28: 10K; 0603-RES
R7: 330; 0603-RES
R14: 5.62k; 0603-RES
R15: 15K; 0603-RES
R16: 22K; 0603-RES
R17: 2.2; 0603-RES
R18, R19: 240; 0603-RES
R20, R21: 390; 0603-RES
R25, R26: 4.7K; 0603-RES
R27: 33; 0603-RES
R29: 1M; 0603-RES
S1: RESET; TACTILE-SWITCH-SMD
S2: DNS; TACTILE-PTH-SIDEEZ
SJ1, SJ2, SJ3: JUMPER-PAD-2-NC_BY_TRACE; PAD-JUMPER-2-NC_BY_TRACE_YES_SILK
STANDOFF1, STANDOFF2, STANDOFF3, STANDOFF4: STAND-OFF
TP1: Trigger; 1X02_NO_SILK
TP2: I2S TP; 1X07_NO_SILK
TP3: SD TP; 1X04_NO_SILK
U1: ATSAMS70NXXA-AN; LQFP100
U2: AK4618VQSFE-PACKAGE; LQFP-48
U3, U4: LM1117; SOT223
Y1: 12MHz; CRYSTAL-SMD-5X3

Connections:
3.3V: C7.1, C11.1, C12.1, C13.1, C16.1, C33.1, C43.1, C44.1, C45.1, C46.1, C47.1, C48.1, J1.1 (VCC), J10.P$1, JP2.21, JP2.23, JP5.VCC, L3.1, R1.2, R2.2, R3.2, R4.2, R5.2, R6.2, R7.2, R17.1, R19.2, R22.2, R23.2, R24.2, R25.2, R26.2, R28.2, SJ3.1, SJ3.2, U1.5 (VDDIN), U1.19 (VDDIO), U1.28 (VDDIO), U1.68 (VDDIO), U1.81 (VDDIO), U1.93 (VDDUTMII), U2.39 (TVDD), U4.2 (OUT), U4.4 (OUT)
3.3V_A: C9.1, C14.1, C17.1, C18.1, C19.1, J9.P$1, JP4.20, R18.2, SJ2.1, SJ2.2, U2.18 (AVDD1), U2.37 (AVDD2), U3.2 (OUT), U3.4 (OUT)
AIN1L: C25.1, JP4.13
AIN1R: C26.1, JP4.15
AIN2L: C37.1, JP4.17
AIN2R: C38.1, JP4.19
AOUT1L: C21.2, JP4.1, R8.2
AOUT1R: C22.2, JP4.3, R9.2
AOUT2L: C23.2, JP4.5, R10.2
AOUT2R: C24.2, JP4.7, R11.2
AOUT3L: C27.2, JP4.9, R12.2
AOUT3R: C28.2, JP4.11, R13.2
APDN: TP2.7, U1.70 (PA01), U2.8 (PDN)
BCLK: TP2.3, U1.11 (PB01), U2.48 (BICK)
DBUG: TP1.2, U1.72 (PA00)
GND: C1.2, C2.2, C3.2, C4.2, C5.2, C6.2, C7.2, C8.2, C9.2, C10.2, C11.2, C12.2, C13.2, C14.2, C15.2, C16.2, C17.2, C18.2, C19.2, C20.2, C29.2, C30.2, C33.2, C34.2, C35.2, C36.2, C39.2, C40.2, C41.2, C42.2, C43.2, C44.2, C45.2, C46.2, C47.2, C48.2, J1.3 (GND), J1.5 (GND), J1.9 (GNDDTCT), J2.GND, J2.GNDBREAK, JP1.GND, JP2.25, JP2.26, JP4.2, JP4.4, JP4.6, JP4.8, JP4.10, JP4.12, JP4.14, JP4.16, JP4.18, JP5.GND, JP5.GND1 (SHIELD), JP5.GND3 (SHIELD), R8.1, R9.1, R10.1, R11.1, R12.1, R13.1, R14.1, R16.1, R20.1, R21.1, R29.1, S1.1, S2.1, SJ1.1, SJ1.2, TP1.1, TP2.1, TP3.1, U1.3 (GND), U1.6 (VREFN), U1.7 (GND), U1.8 (GND), U1.10 (GND), U1.29 (GND), U1.67 (GND), U2.2 (STDI6/TDMI), U2.3 (STDI5), U2.4 (STDI4), U2.5 (STDI3), U2.6 (STDI2), U2.19 (VSS1), U2.38 (VSS2), U2.40 (VSS3)
HSDM: JP1.D-, U1.94 (HSDM)
HSDP: JP1.D+, U1.95 (HSDP)
I2C_SCK: R26.1, U1.55 (PA04), U2.46 (SCL)
I2C_SDA: R25.1, U1.64 (PA03), U2.45 (SDA)
LRCK: TP2.4, U1.12 (PB00), U2.1 (LRCLK)
MCLK: TP2.2, U1.15 (PA18), U2.47 (MCLK)
MIN: JP2.18, U1.75 (PD15)
MOUT: JP2.20, U1.56 (PD16)
unnamed: C2.1, U1.98 (PB08), Y1.3 (2)
unnamed: C1.1, U1.99 (PB09), Y1.1
unnamed: C3.1, L1.1, U1.96 (VDDUTMIC)
unnamed: C29.1, L4.2, U1.90 (VDDPLLUSB)
unnamed: C4.1, L2.1, U1.86 (VDDPLL)
unnamed: C15.1, U2.41 (REGO)
unnamed: C36.1, D2.A, JP1.VBUS, R15.2
unnamed: C8.1, C10.1, D2.C, Q1.2 (S), U3.3 (IN), U4.3 (IN)
unnamed: D1.C, U1.31 (PA23)
unnamed: D1.A, R7.1
unnamed: C20.1, U2.20 (VCOM)
unnamed: C21.1, U2.36 (LOUT1)
unnamed: C26.2, U2.12 (IN2/IN2P)
unnamed: C25.2, U2.10 (IN1/IN1P)
unnamed: C34.1, R14.2, U1.97 (VBG)
unnamed: C35.1, L3.2, U1.9 (VREFP)
unnamed: C22.1, U2.35 (ROUT1)
unnamed: C23.1, U2.34 (LOUT2)
unnamed: C24.1, U2.33 (ROUT2)
unnamed: C27.1, U2.32 (LOUT3)
unnamed: C28.1, U2.31 (ROUT3)
unnamed: C37.2, U2.13 (IN3N)
unnamed: L4.1, R17.2
unnamed: R18.1, R20.2, U3.1 (ADJ)
unnamed: R27.1, S1.3 (2), S2.2
unnamed: C38.2, U2.15 (IN4N)
unnamed: J7.P$1, U2.23 (IN6N)
unnamed: R19.1, R21.2, U4.1 (ADJ)
unnamed: J8.P$1, U2.21 (IN5N)
unnamed: J3.P$1, U2.30 (LOUT4)
unnamed: J4.P$1, U2.29 (ROUT4)
unnamed: J5.P$1, U2.28 (LOUT5)
unnamed: J6.P$1, U2.27 (ROUT5)
unnamed: J12.P$1, U1.14 (PA19)
unnamed: J13.P$1, U1.13 (PA20)
unnamed: Q1.1 (G), R29.2
NRESET: C30.1, J1.10 (NRESET), R24.1, R27.2, R28.1, U1.58 (NRST)
RXD: JP2.17, U1.51 (PD28)
SDCD: JP5.CD1, JP5.CD2, R6.1, U1.49 (PD18)
SDCLK: JP5.CLK, TP3.4, U1.40 (PA25)
SDCMD: JP5.CMD, R5.1, TP3.3, U1.79 (PA28)
SDD0: JP5.DAT0, R3.1, TP3.2, U1.82 (PA30)
SDD1: JP5.DAT1, R4.1, U1.83 (PA31)
SDD2: JP5.DAT2, R1.1, U1.42 (PA26)
SDD3: JP5.CD/DAT3, R2.1, U1.50 (PA27)
SWCLK/TCK: J1.4 (SWDCLK/TCK), R23.1, U1.63 (PB07)
SWDIO/TMS: J1.2 (SWDIO/TMS), R22.1, U1.57 (PB06)
TDI: J1.8 (NC/TDI), U1.74 (PB04)
TDMI: TP2.6, U1.46 (PA10), U2.42 (STDO1)
TDMO: TP2.5, U1.36 (PD26), U2.7 (STDI1)
TDO: J1.6 (SWO/TDO), U1.77 (PB05)
TXD: JP2.19, U1.23 (PD30)
UIA0: JP2.1, U1.17 (PB02)
UIA1: JP2.2, U1.20 (PB03)
UIA2: JP2.3, U1.21 (PA21)
UIA3: JP2.4, U1.16 (PA17)
UID0: JP2.5, U1.1 (PD00)
UID1: JP2.6, U1.92 (PD01)
UID2: JP2.7, U1.91 (PD02)
UID3: JP2.8, U1.89 (PD03)
UID4: JP2.9, U1.88 (PD04)
UID5: JP2.10, U1.87 (PD05)
UID6: JP2.11, U1.85 (PD06)
UID7: JP2.12, U1.84 (PD07)
UID8: JP2.13, U1.80 (PD08)
UID9: JP2.14, U1.78 (PD09)
UID10: JP2.15, U1.71 (PD10)
UID11: JP2.16, U1.69 (PD11)
VBDET: R15.1, R16.2, U1.47 (PD19)
VDDOUT: C5.1, C6.1, C39.1, C40.1, C41.1, C42.1, L1.2, L2.2, U1.4 (VDDOUT), U1.18 (VDDCORE), U1.22 (VDDCORE), U1.39 (VDDCORE), U1.76 (VDDCORE)
VIN: J2.PWR, J11.P$1, JP2.22, JP2.24, Q1.3 (D)

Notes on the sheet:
Isolated analog ground plane with single connection to digital ground
Jamie Robertson & Byron Jacquot
V01
Near each VDDCORE pin
Near each VDDIO pin
Near VDDUTMII
Near VDDIN
Near VDDOUT
Power Regulators
USB Device Port
Scope Trigger
I2S Test Points
Cortex Debug Port
Cortex M7 Processor
Audio Codec
SDIO uSD Card Slot
User Input Pins
Reset Switch
S2 is optional, side-firing 6mm tact type.
Vin range: 5 to 15 VDC
Status LED
Power inputs prioritize barrel over USB. If 5V is present on both, current is drawn from barrel.

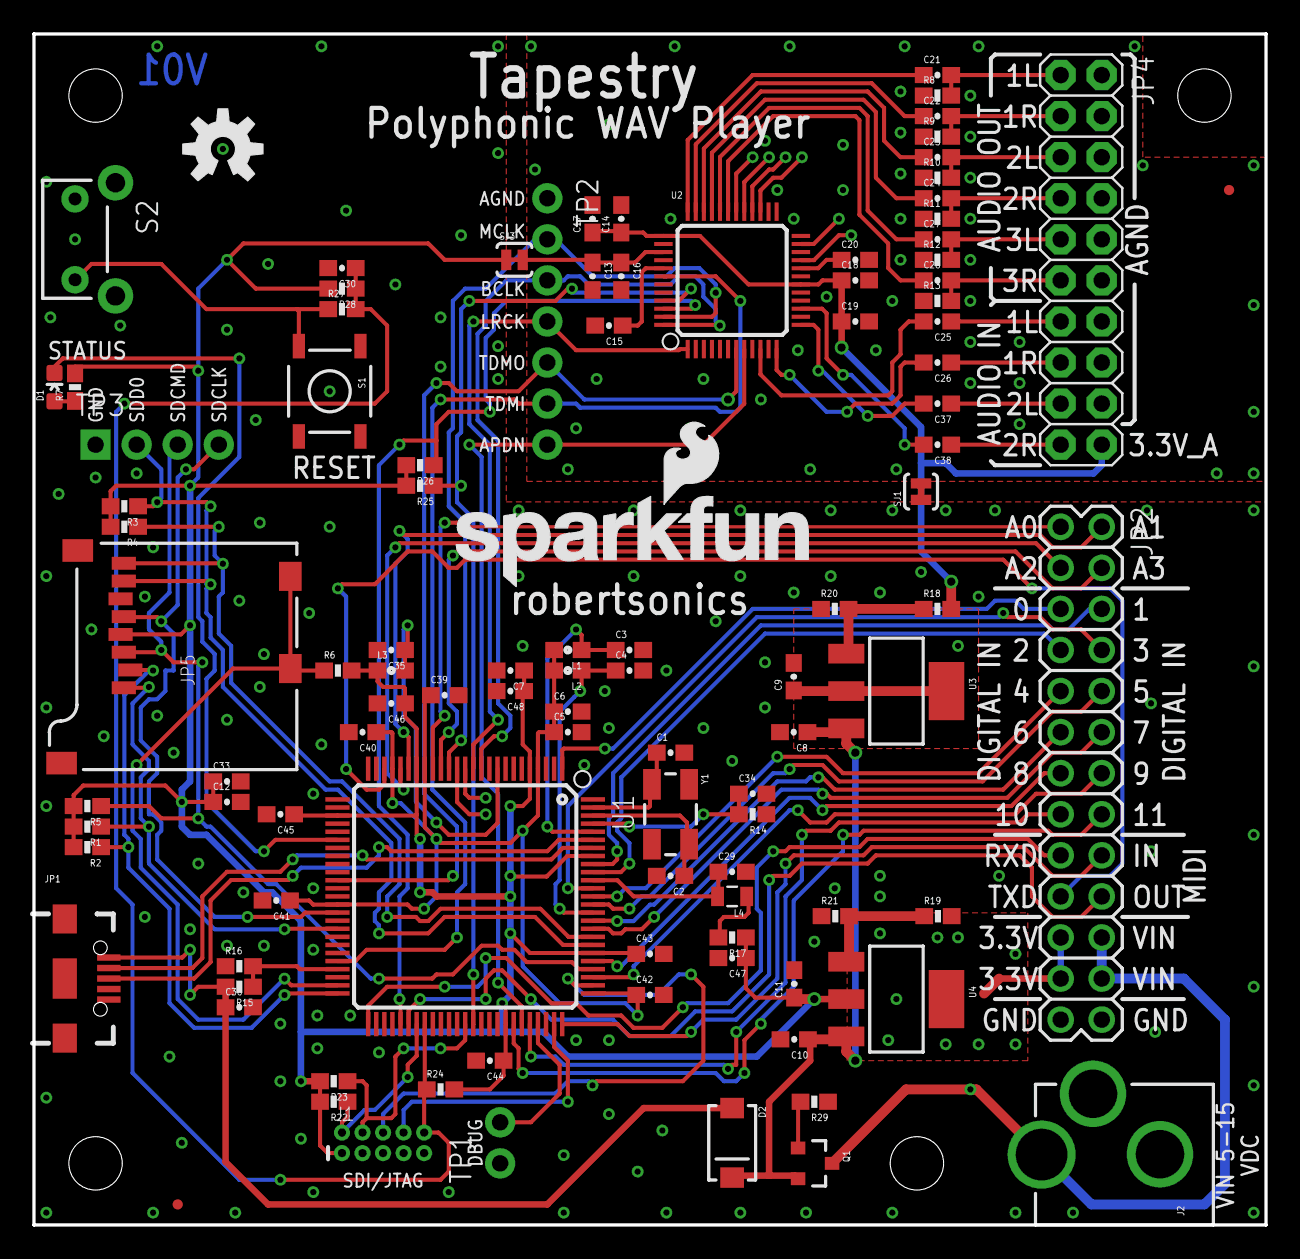
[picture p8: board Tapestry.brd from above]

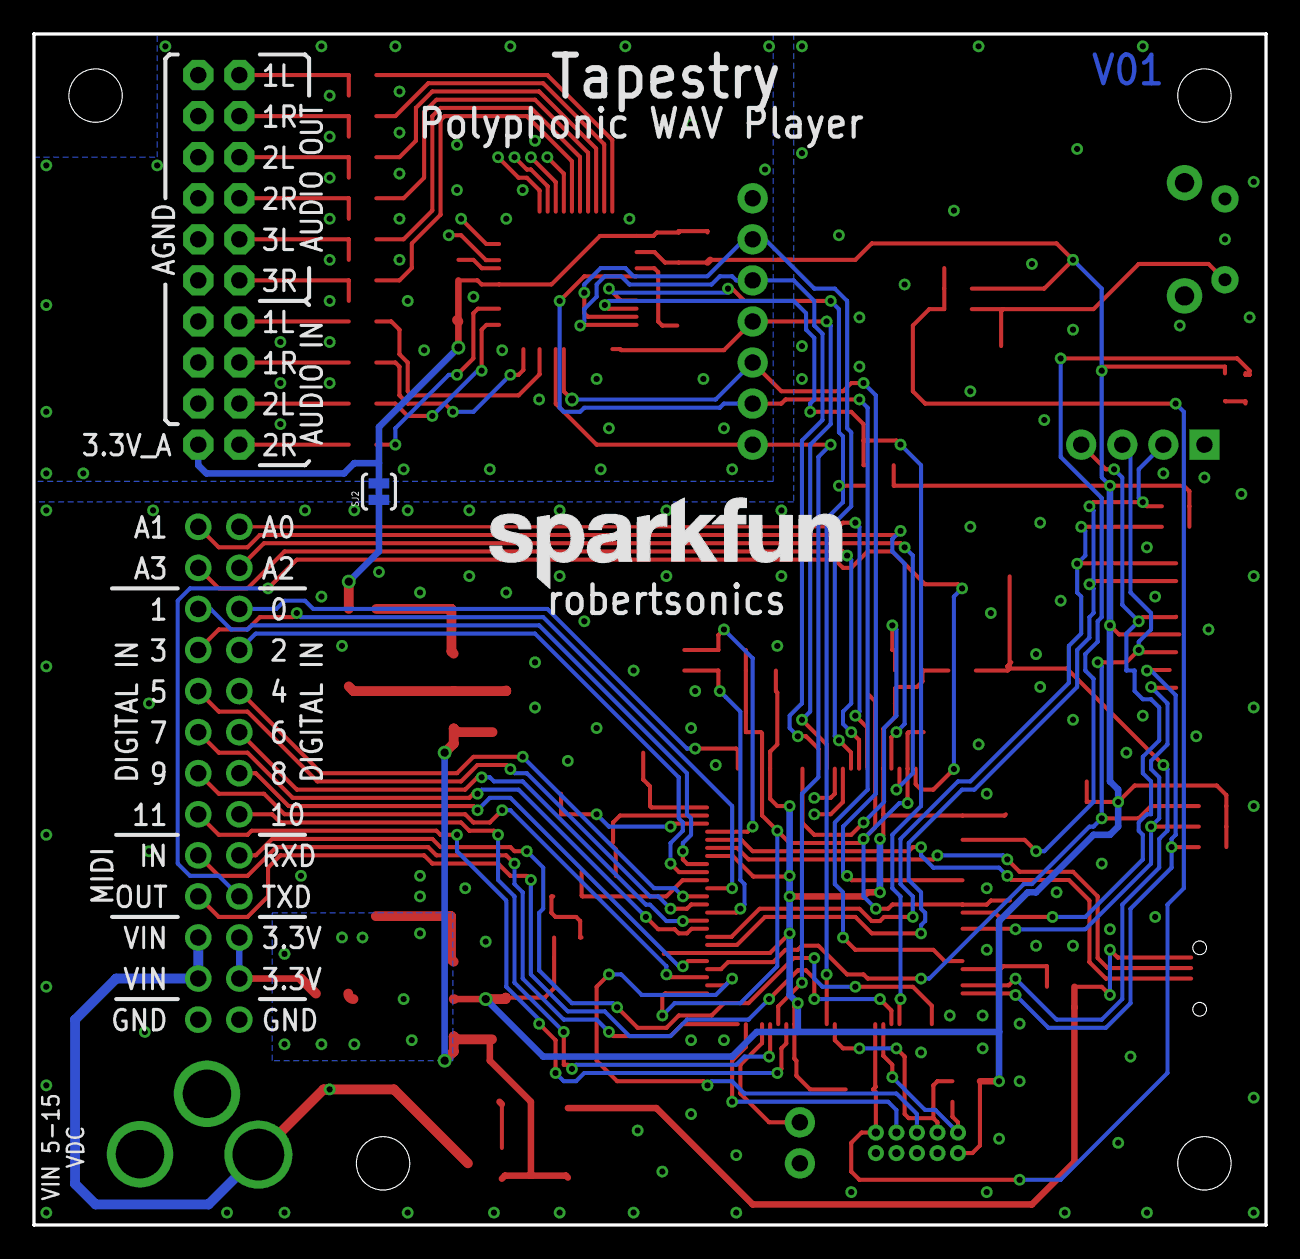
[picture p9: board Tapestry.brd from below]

Board: 2 copper layers, 76.2 x 73.7 mm, 122 parts (2 on the bottom side), 95 nets.

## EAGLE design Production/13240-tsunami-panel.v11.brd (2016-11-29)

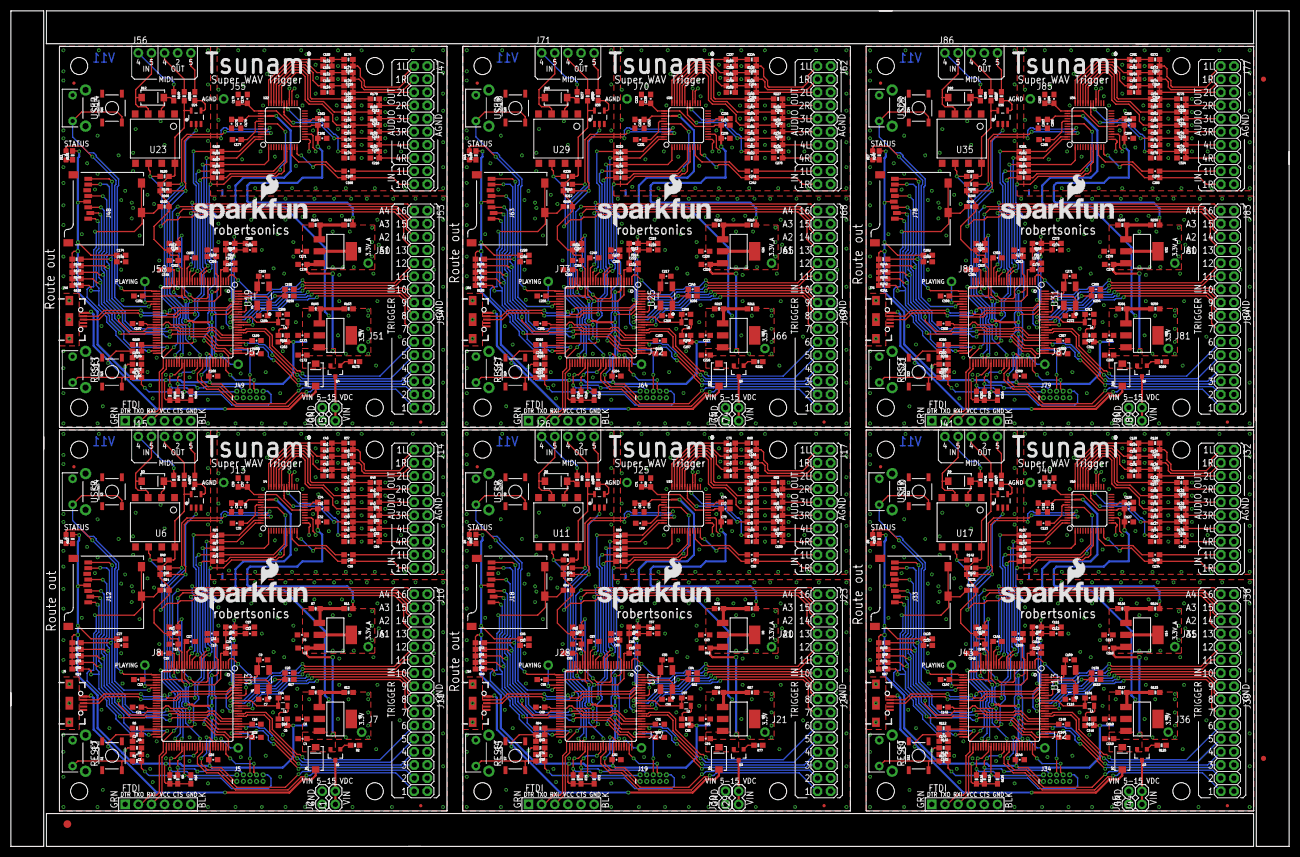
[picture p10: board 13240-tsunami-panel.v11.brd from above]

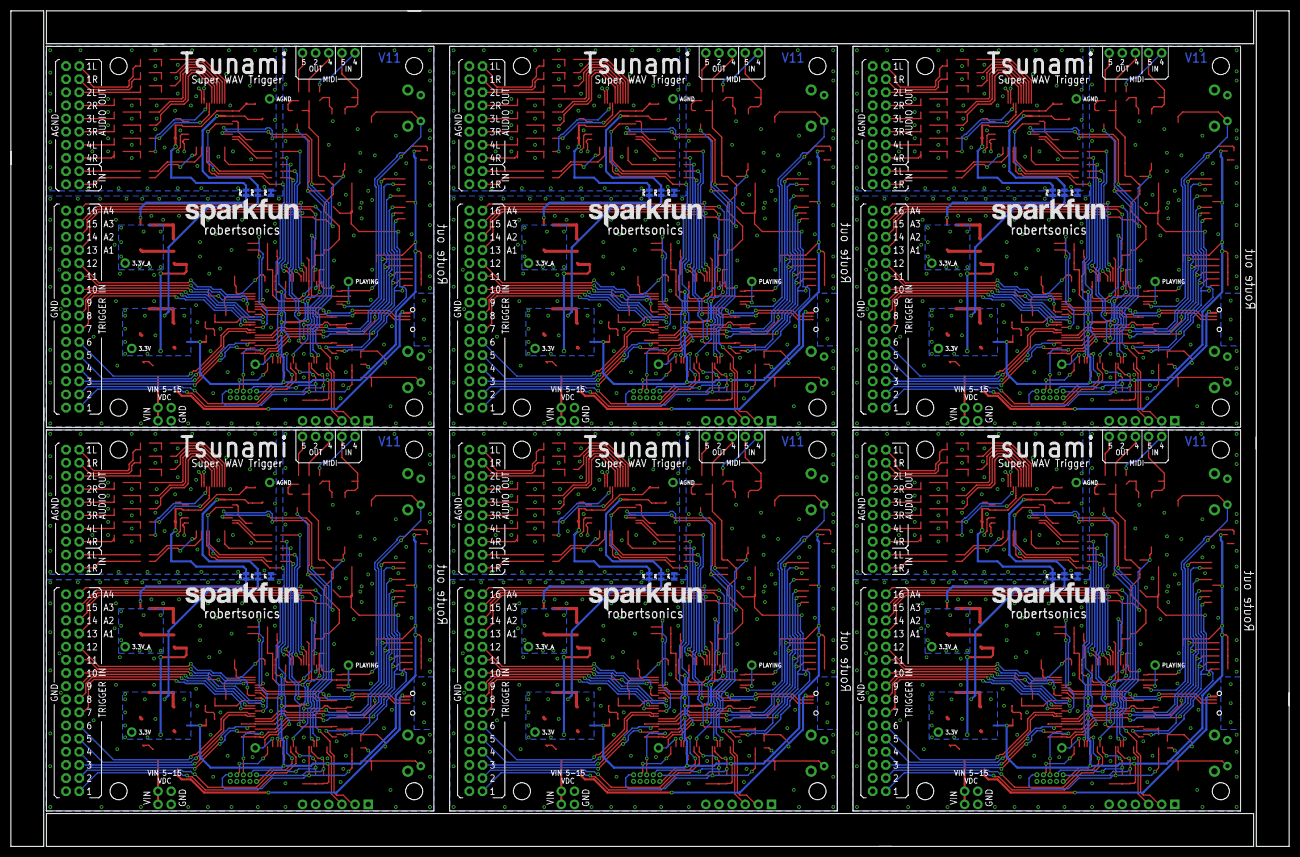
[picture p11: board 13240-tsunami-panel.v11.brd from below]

Board: 2 copper layers, 247.1 x 161.5 mm, 939 parts (24 on the bottom side), 678 nets.

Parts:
C1, C98, C152, C206, C260, C314: 10nF; 0603-CAP
C2, C5, C6, C11, C27, C61, C63, C65, C66, C86, C115, C117, C119, C120, C140, C169, C171, C173, C174, C194, C223, C225, C227, C228, C248, C277, C279, C281, C282, C302: 10uF; 0603-CAP
C3, C4, C8, C10, C12, C13, C15, C16, C17, C18, C19, C21, C22, C23, C24, C26, C28, C31, C35, C37, C47, C48, C49, C50, C51, C52, C53, C54, C57, C58, C59, C62, C64, C68, C70, C72, C83, C85, C87, C88, C89, C90, C91, C92, C93, C94, C95, C96, C101, C102, C103, C104, C105, C106, C107, C108, C111, C112, C113, C116, C118, C122, C124, C126, C137, C139, C141, C142, C143, C144, C145, C146, C147, C148, C149, C150, C155, C156, C157, C158, C159, C160, C161, C162, C165, C166, C167, C170, C172, C176, C178, C180, C191, C193, C195, C196, C197, C198, C199, C200, C201, C202, C203, C204, C209, C210, C211, C212, C213, C214, C215, C216, C219, C220, C221, C224, C226, C230, C232, C234, C245, C247, C249, C250, C251, C252, C253, C254, C255, C256, C257, C258, C263, C264, C265, C266, C267, C268, C269, C270, C273, C274, C275, C278, C280, C284, C286, C288, C299, C301, C303, C304, C305, C306, C307, C308, C309, C310, C311, C312, C317, C318, C319, C320, C321, C322, C323, C324: 0.1uF; 0603-CAP
C7, C9, C55, C56, C109, C110, C163, C164, C217, C218, C271, C272: 12pF; 0603-CAP
C14, C97, C151, C205, C259, C313: 4.7uF; 0603-CAP
C20, C84, C138, C192, C246, C300: 10pF; 0603-CAP
C25, C60, C114, C168, C222, C276: 2.2uF; 0603-CAP
C29, C30, C32, C33, C34, C36, C38, C39, C40, C41, C42, C43, C44, C45, C46, C67, C69, C71, C73, C74, C75, C76, C77, C78, C79, C80, C81, C82, C99, C100, C121, C123, C125, C127, C128, C129, C130, C131, C132, C133, C134, C135, C136, C153, C154, C175, C177, C179, C181, C182, C183, C184, C185, C186, C187, C188, C189, C190, C207, C208, C229, C231, C233, C235, C236, C237, C238, C239, C240, C241, C242, C243, C244, C261, C262, C283, C285, C287, C289, C290, C291, C292, C293, C294, C295, C296, C297, C298, C315, C316: 1.0uF; 0603-CAP
D1, D3, D4, D6, D7, D9, D10, D12, D13, D15, D16, D18: MBRA140; SMA-DIODE
D2, D5, D8, D11, D14, D17: BLUE; LED-0603
E$1: FIDUCIAL-1.5X3
E$7, E$8: FIDUCIAL-1X2
FB1, FB2, FB3, FB4, FB5, FB6, FB7, FB8, FB9, FB10, FB11, FB12, FB13, FB14, FB15, FB16, FB17, FB18: 470; 0603
FD1, FD2, FD3, FD4, FD5, FD6, FD7, FD8, FD9, FD10, FD11, FD12: FIDUCIALUFIDUCIAL; MICRO-FIDUCIAL
H1, H2, H3, H4, H5, H6, H7, H8, H9, H10, H11, H12, H13, H14, H15, H16, H17, H18, H19, H20, H21, H22, H23, H24: STAND-OFF
J1, J29, J44, J59, J74, J89: VDC-IN; 1X02
J2, J30, J45, J60, J75, J90: GND-IN; 1X02
J3, J27, J42, J57, J72, J87: DEBUG; 1X01_NO_SILK
J4, J16, J31, J46, J61, J76: USB-MICROB"; USB-B-MICRO-SMD_V03
J5, J19, J34, J49, J64, J79: CORTEX_DEBUGPTH; 2X5-PTH-1.27MM
J6, J20, J35, J50, J65, J80: 3.3VA; 1X01_NO_SILK
J7, J21, J36, J51, J66, J81: 3.3V; 1X01_NO_SILK
J8, J28, J43, J58, J73, J88: PLAYING; 1X01_NO_SILK
J9, J22, J37, J52, J67, J82: FTDI_DEVICE; FTDI_DEVICE_SIDE
J10, J23, J38, J53, J68, J83: TRIG2; 2X8
J11, J24, J39, J54, J69, J84: TRIG1; 2X8
J12, J18, J33, J48, J63, J78: USD-SDIO-SOCKET; MICRO-SD-SOCKET-SDIO
J13, J25, J40, J55, J70, J85: GND; 1X01_NO_SILK
J14, J17, J32, J47, J62, J77: AUDIO I/O; 2X10
J15, J26, J41, J56, J71, J86: MIDI; 1X05_NO_SILK
JP1, JP2, JP3, JP4, JP5, JP6, JP7, JP8, JP9, JP10, JP11, JP12, JP13, JP14, JP15, JP16, JP17, JP18: JUMPER-PAD-2-NC_BY_TRACENO_SILK; PAD-JUMPER-2-NC_BY_TRACE_NO_SILK
L1, L2, L3, L4, L5, L6: 10uH; 0805
LOGO1, LOGO2, LOGO5, LOGO7, LOGO9, LOGO11: SFE_LOGO_NAME.2_INCH; SFE_LOGO_NAME_.2
LOGO3, LOGO4, LOGO6, LOGO8, LOGO10, LOGO12: SFE_LOGO_NAME_FLAME.2_INCH; SFE_LOGO_NAME_FLAME_.2
Q1, Q2, Q3, Q4, Q5, Q6: 2.5A/30V; SOT23-3
R1, R75, R123, R171, R219, R267: 33; 0603-RES
R2, R77, R125, R173, R221, R269: 1M; 0603-RES
R3, R18, R23, R53, R54, R76, R101, R102, R124, R149, R150, R172, R197, R198, R220, R245, R246, R268: 10K; 0603-RES
R4, R63, R111, R159, R207, R255: 15K; 0603-RES
R5, R64, R112, R160, R208, R256: 22K; 0603-RES
R6, R9, R10, R19, R20, R21, R22, R29, R30, R31, R32, R33, R34, R35, R36, R49, R50, R51, R52, R56, R57, R58, R59, R60, R61, R70, R71, R72, R78, R79, R97, R98, R99, R100, R104, R105, R106, R107, R108, R109, R118, R119, R120, R126, R127, R145, R146, R147, R148, R152, R153, R154, R155, R156, R157, R166, R167, R168, R174, R175, R193, R194, R195, R196, R200, R201, R202, R203, R204, R205, R214, R215, R216, R222, R223, R241, R242, R243, R244, R248, R249, R250, R251, R252, R253, R262, R263, R264, R270, R271: 100k; 0603-RES
R7, R8, R68, R69, R116, R117, R164, R165, R212, R213, R260, R261: 390; 0603-RES
R11, R12, R66, R67, R114, R115, R162, R163, R210, R211, R258, R259: 240; 0603-RES
R13, R55, R103, R151, R199, R247: 330; 0603-RES
R14, R15, R73, R74, R121, R122, R169, R170, R217, R218, R265, R266: 4.7K; 0603-RES
R16, R65, R113, R161, R209, R257: 2.2; 0603-RES
R17, R62, R110, R158, R206, R254: 5.62k; 0603-RES
R24, R25, R26, R27, R28, R88, R89, R90, R91, R92, R136, R137, R138, R139, R140, R184, R185, R186, R187, R188, R232, R233, R234, R235, R236, R280, R281, R282, R283, R284: 100; 0603-RES
R37, R38, R39, R40, R41, R42, R43, R44, R80, R81, R82, R83, R84, R85, R86, R87, R128, R129, R130, R131, R132, R133, R134, R135, R176, R177, R178, R179, R180, R181, R182, R183, R224, R225, R226, R227, R228, R229, R230, R231, R272, R273, R274, R275, R276, R277, R278, R279: 10; 0603-RES
R45, R46, R47, R48, R93, R94, R95, R96, R141, R142, R143, R144, R189, R190, R191, R192, R237, R238, R239, R240, R285, R286, R287, R288: 220; 0603-RES
S1, S7, S11, S15, S19, S23: Reset; TACTILE-SWITCH-SMD
S2, S4, S5, S6, S9, S10, S13, S14, S17, S18, S21, S22: DNS; TACTILE-PTH-SIDEEZ
S3, S8, S12, S16, S20, S24: User; TACTILE-SWITCH-SMD
TP1, TP12, TP21, TP30, TP39, TP48: AIN2L; TP_15TH
TP2, TP13, TP22, TP31, TP40, TP49: AIN2R; TP_15TH
TP3, TP10, TP19, TP28, TP37, TP46: AOUT5L; TP_15TH
TP4, TP11, TP20, TP29, TP38, TP47: AOUT5R; TP_15TH
TP5, TP14, TP23, TP32, TP41, TP50: SWDIO/TMS; TP_15TH
TP6, TP15, TP24, TP33, TP42, TP51: SWCK/TCK; TP_15TH
TP7, TP16, TP25, TP34, TP43, TP52: TDO; TP_15TH
TP8, TP17, TP26, TP35, TP44, TP53: TDI; TP_15TH
TP9, TP18, TP27, TP36, TP45, TP54: NRESET; TP_15TH
U1, U2, U8, U9, U14, U15, U20, U21, U26, U27, U32, U33: LM1117; SOT223
U3, U7, U13, U19, U25, U31: ATSAMS70N20A-AN; LQFP100
U4, U10, U16, U22, U28, U34: AK4618VQ; LQFP-48
U5, U12, U18, U24, U30, U36: 74AHC1G125; SOT23-5
U6, U11, U17, U23, U29, U35: 6N138M; 8-SMD
Y1, Y2, Y3, Y4, Y5, Y6: 11.2896 MHz; CRYSTAL-OSC-SMD-5X3

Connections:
1: D6.C, R93.2, U11.2
2: D9.C, R141.2, U17.2
3: D12.C, R189.2, U23.2
3.3V: C6.1, C8.1, C10.1, C11.1, C12.1, C13.1, C15.1, C16.1, C27.1, C28.1, C35.1, C36.1, FB3.1, J5.1, J7.1, J12.VCC, JP2.1, JP2.2, R3.2, R6.2, R9.2, R10.2, R12.2, R13.2, R14.2, R15.2, R16.1, R18.2, R19.2, R20.2, R21.2, R22.2, R23.2, R47.2, R48.2, U2.2, U2.4, U3.5, U3.19, U3.28, U3.68, U3.81, U3.93, U4.39, U5.5, U6.8
3.3V1: C61.1, C65.1, C66.1, C67.1, C70.1, C83.1, C91.1, C92.1, C93.1, C94.1, C95.1, C96.1, FB6.1, J18.VCC, J19.1, J21.1, JP6.1, JP6.2, R49.2, R50.2, R51.2, R52.2, R53.2, R54.2, R55.2, R65.1, R67.2, R70.2, R71.2, R72.2, R73.2, R74.2, R76.2, R94.2, R95.2, U7.5, U7.19, U7.28, U7.68, U7.81, U7.93, U9.2, U9.4, U10.39, U11.8, U12.5
3.3V2: C115.1, C119.1, C120.1, C121.1, C124.1, C137.1, C145.1, C146.1, C147.1, C148.1, C149.1, C150.1, FB9.1, J33.VCC, J34.1, J36.1, JP9.1, JP9.2, R97.2, R98.2, R99.2, R100.2, R101.2, R102.2, R103.2, R113.1, R115.2, R118.2, R119.2, R120.2, R121.2, R122.2, R124.2, R142.2, R143.2, U13.5, U13.19, U13.28, U13.68, U13.81, U13.93, U15.2, U15.4, U16.39, U17.8, U18.5
3.3V3: C169.1, C173.1, C174.1, C175.1, C178.1, C191.1, C199.1, C200.1, C201.1, C202.1, C203.1, C204.1, FB12.1, J48.VCC, J49.1, J51.1, JP12.1, JP12.2, R145.2, R146.2, R147.2, R148.2, R149.2, R150.2, R151.2, R161.1, R163.2, R166.2, R167.2, R168.2, R169.2, R170.2, R172.2, R190.2, R191.2, U19.5, U19.19, U19.28, U19.68, U19.81, U19.93, U21.2, U21.4, U22.39, U23.8, U24.5
3.3V4: C223.1, C227.1, C228.1, C229.1, C232.1, C245.1, C253.1, C254.1, C255.1, C256.1, C257.1, C258.1, FB15.1, J63.VCC, J64.1, J66.1, JP15.1, JP15.2, R193.2, R194.2, R195.2, R196.2, R197.2, R198.2, R199.2, R209.1, R211.2, R214.2, R215.2, R216.2, R217.2, R218.2, R220.2, R238.2, R239.2, U25.5, U25.19, U25.28, U25.68, U25.81, U25.93, U27.2, U27.4, U28.39, U29.8, U30.5
3.3V5: C277.1, C281.1, C282.1, C283.1, C286.1, C299.1, C307.1, C308.1, C309.1, C310.1, C311.1, C312.1, FB18.1, J78.VCC, J79.1, J81.1, JP18.1, JP18.2, R241.2, R242.2, R243.2, R244.2, R245.2, R246.2, R247.2, R257.1, R259.2, R262.2, R263.2, R264.2, R265.2, R266.2, R268.2, R286.2, R287.2, U31.5, U31.19, U31.28, U31.68, U31.81, U31.93, U33.2, U33.4, U34.39, U35.8, U36.5
4: D15.C, R237.2, U29.2
5: D18.C, R285.2, U35.2
56: D3.C, R45.2, U6.2
AIN1L: C29.1, J14.17
AIN1L1: C79.1, J17.17
AIN1L2: C133.1, J32.17
AIN1L3: C187.1, J47.17
AIN1L4: C241.1, J62.17
AIN1L5: C295.1, J77.17
AIN1R: C30.1, J14.19
AIN1R1: C80.1, J17.19
AIN1R2: C134.1, J32.19
AIN1R3: C188.1, J47.19
AIN1R4: C242.1, J62.19
AIN1R5: C296.1, J77.19
AIN2L: TP1.P$1, U4.13
AIN2L1: TP12.P$1, U10.13
AIN2L2: TP21.P$1, U16.13
AIN2L3: TP30.P$1, U22.13
AIN2L4: TP39.P$1, U28.13
AIN2L5: TP48.P$1, U34.13
AIN2R: TP2.P$1, U4.15
AIN2R1: TP13.P$1, U10.15
AIN2R2: TP22.P$1, U16.15
AIN2R3: TP31.P$1, U22.15
AIN2R4: TP40.P$1, U28.15
AIN2R5: TP49.P$1, U34.15
AOUT1L: C47.1, J14.1, R37.2
AOUT1L1: C101.1, J17.1, R80.2
AOUT1L2: C155.1, J32.1, R128.2
AOUT1L3: C209.1, J47.1, R176.2
AOUT1L4: C263.1, J62.1, R224.2
AOUT1L5: C317.1, J77.1, R272.2
AOUT1R: C48.1, J14.3, R38.2
AOUT1R1: C102.1, J17.3, R81.2
AOUT1R2: C156.1, J32.3, R129.2
AOUT1R3: C210.1, J47.3, R177.2
AOUT1R4: C264.1, J62.3, R225.2
AOUT1R5: C318.1, J77.3, R273.2
AOUT2L: C49.1, J14.5, R39.2
AOUT2L1: C103.1, J17.5, R82.2
AOUT2L2: C157.1, J32.5, R130.2
AOUT2L3: C211.1, J47.5, R178.2
AOUT2L4: C265.1, J62.5, R226.2
AOUT2L5: C319.1, J77.5, R274.2
AOUT2R: C50.1, J14.7, R40.2
AOUT2R1: C104.1, J17.7, R83.2
AOUT2R2: C158.1, J32.7, R131.2
AOUT2R3: C212.1, J47.7, R179.2
AOUT2R4: C266.1, J62.7, R227.2
AOUT2R5: C320.1, J77.7, R275.2
AOUT3L: C51.1, J14.9, R41.2
AOUT3L1: C105.1, J17.9, R84.2
AOUT3L2: C159.1, J32.9, R132.2
AOUT3L3: C213.1, J47.9, R180.2
AOUT3L4: C267.1, J62.9, R228.2
AOUT3L5: C321.1, J77.9, R276.2
AOUT3R: C52.1, J14.11, R42.2
AOUT3R1: C106.1, J17.11, R85.2
AOUT3R2: C160.1, J32.11, R133.2
AOUT3R3: C214.1, J47.11, R181.2
AOUT3R4: C268.1, J62.11, R229.2
AOUT3R5: C322.1, J77.11, R277.2
AOUT4L: C53.1, J14.13, R43.2
AOUT4L1: C107.1, J17.13, R86.2
AOUT4L2: C161.1, J32.13, R134.2
AOUT4L3: C215.1, J47.13, R182.2
AOUT4L4: C269.1, J62.13, R230.2
AOUT4L5: C323.1, J77.13, R278.2
AOUT4R: C54.1, J14.15, R44.2
AOUT4R1: C108.1, J17.15, R87.2
AOUT4R2: C162.1, J32.15, R135.2
AOUT4R3: C216.1, J47.15, R183.2
AOUT4R4: C270.1, J62.15, R231.2
AOUT4R5: C324.1, J77.15, R279.2
APDN: U3.70, U4.8
APDN1: U7.70, U10.8
APDN2: U13.70, U16.8
APDN3: U19.70, U22.8
APDN4: U25.70, U28.8
APDN5: U31.70, U34.8
BCLK: R26.1, U3.11
BCLK1: R90.1, U7.11
BCLK2: R138.1, U13.11
BCLK3: R186.1, U19.11
BCLK4: R234.1, U25.11
BCLK5: R282.1, U31.11
BCLK_C: R26.2, U4.48
BCLK_C1: R90.2, U10.48
BCLK_C2: R138.2, U16.48
BCLK_C3: R186.2, U22.48
BCLK_C4: R234.2, U28.48
BCLK_C5: R282.2, U34.48
DBUG: J3.1, U3.72
DBUG1: J27.1, U7.72
DBUG2: J42.1, U13.72
DBUG3: J57.1, U19.72
DBUG4: J72.1, U25.72
DBUG5: J87.1, U31.72
GND: C1.2, C2.2, C3.2, C4.2, C5.2, C6.2, C7.2, C8.2, C9.2, C10.2, C11.2, C12.2, C13.2, C14.2, C15.2, C16.2, C17.2, C18.2, C19.2, C20.2, C21.2, C22.2, C23.2, C24.2, C25.2, C26.2, C27.2, C28.2, C31.2, C32.2, C33.2, C34.2, C35.2, C36.2, C37.2, C38.2, C47.2, C48.2, C49.2, C50.2, C51.2, C52.2, C53.2, C54.2, J2.1, J2.2, J4.GND, J5.3, J5.5, J5.9, J9.P$6, J10.2, J10.4, J10.6, J10.8, J10.10, J10.12, J10.14, J10.16, J11.2, J11.4, J11.6, J11.8, J11.10, J11.12, J11.14, J11.16, J12.GND, J12.GND1, J12.GND3, J13.1, J14.2, J14.4, J14.6, J14.8, J14.10, J14.12, J14.14, J14.16, J14.18, J14.20, J15.4, JP3.1, JP3.2, R2.1, R5.1, R7.1, R8.1, R17.1, R29.1, R30.1, R31.1, R32.1, R33.1, R34.1, R35.1, R36.1, S1.1, S2.1, S3.1, S4.1, U3.3, U3.6, U3.7, U3.8, U3.10, U3.29, U3.67, U4.2, U4.3, U4.4, U4.5, U4.6, U4.19, U4.38, U4.40, U5.1, U5.3, U6.5, Y1.2, Y1.4
GND1: C55.2, C56.2, C57.2, C58.2, C59.2, C60.2, C61.2, C62.2, C63.2, C64.2, C65.2, C66.2, C67.2, C68.2, C69.2, C70.2, C71.2, C72.2, C73.2, C74.2, C83.2, C84.2, C85.2, C86.2, C87.2, C88.2, C89.2, C90.2, C91.2, C92.2, C93.2, C94.2, C95.2, C96.2, C97.2, C98.2, C101.2, C102.2, C103.2, C104.2, C105.2, C106.2, C107.2, C108.2, J16.GND, J17.2, J17.4, J17.6, J17.8, J17.10, J17.12, J17.14, J17.16, J17.18, J17.20, J18.GND, J18.GND1, J18.GND3, J19.3, J19.5, J19.9, J22.P$6, J23.2, J23.4, J23.6, J23.8, J23.10, J23.12, J23.14, J23.16, J24.2, J24.4, J24.6, J24.8, J24.10, J24.12, J24.14, J24.16, J25.1, J26.4, J30.1, J30.2, JP4.1, JP4.2, R56.1, R57.1, R58.1, R59.1, R60.1, R61.1, R62.1, R64.1, R68.1, R69.1, R77.1, R78.1, R79.1, S5.1, S6.1, S7.1, S8.1, U7.3, U7.6, U7.7, U7.8, U7.10, U7.29, U7.67, U10.2, U10.3, U10.4, U10.5, U10.6, U10.19, U10.38, U10.40, U11.5, U12.1, U12.3, Y2.2, Y2.4
GND2: C109.2, C110.2, C111.2, C112.2, C113.2, C114.2, C115.2, C116.2, C117.2, C118.2, C119.2, C120.2, C121.2, C122.2, C123.2, C124.2, C125.2, C126.2, C127.2, C128.2, C137.2, C138.2, C139.2, C140.2, C141.2, C142.2, C143.2, C144.2, C145.2, C146.2, C147.2, C148.2, C149.2, C150.2, C151.2, C152.2, C155.2, C156.2, C157.2, C158.2, C159.2, C160.2, C161.2, C162.2, J31.GND, J32.2, J32.4, J32.6, J32.8, J32.10, J32.12, J32.14, J32.16, J32.18, J32.20, J33.GND, J33.GND1, J33.GND3, J34.3, J34.5, J34.9, J37.P$6, J38.2, J38.4, J38.6, J38.8, J38.10, J38.12, J38.14, J38.16, J39.2, J39.4, J39.6, J39.8, J39.10, J39.12, J39.14, J39.16, J40.1, J41.4, J45.1, J45.2, JP7.1, JP7.2, R104.1, R105.1, R106.1, R107.1, R108.1, R109.1, R110.1, R112.1, R116.1, R117.1, R125.1, R126.1, R127.1, S9.1, S10.1, S11.1, S12.1, U13.3, U13.6, U13.7, U13.8, U13.10, U13.29, U13.67, U16.2, U16.3, U16.4, U16.5, U16.6, U16.19, U16.38, U16.40, U17.5, U18.1, U18.3, Y3.2, Y3.4
GND3: C163.2, C164.2, C165.2, C166.2, C167.2, C168.2, C169.2, C170.2, C171.2, C172.2, C173.2, C174.2, C175.2, C176.2, C177.2, C178.2, C179.2, C180.2, C181.2, C182.2, C191.2, C192.2, C193.2, C194.2, C195.2, C196.2, C197.2, C198.2, C199.2, C200.2, C201.2, C202.2, C203.2, C204.2, C205.2, C206.2, C209.2, C210.2, C211.2, C212.2, C213.2, C214.2, C215.2, C216.2, J46.GND, J47.2, J47.4, J47.6, J47.8, J47.10, J47.12, J47.14, J47.16, J47.18, J47.20, J48.GND, J48.GND1, J48.GND3, J49.3, J49.5, J49.9, J52.P$6, J53.2, J53.4, J53.6, J53.8, J53.10, J53.12, J53.14, J53.16, J54.2, J54.4, J54.6, J54.8, J54.10, J54.12, J54.14, J54.16, J55.1, J56.4, J60.1, J60.2, JP10.1, JP10.2, R152.1, R153.1, R154.1, R155.1, R156.1, R157.1, R158.1, R160.1, R164.1, R165.1, R173.1, R174.1, R175.1, S13.1, S14.1, S15.1, S16.1, U19.3, U19.6, U19.7, U19.8, U19.10, U19.29, U19.67, U22.2, U22.3, U22.4, U22.5, U22.6, U22.19, U22.38, U22.40, U23.5, U24.1, U24.3, Y4.2, Y4.4
GND4: C217.2, C218.2, C219.2, C220.2, C221.2, C222.2, C223.2, C224.2, C225.2, C226.2, C227.2, C228.2, C229.2, C230.2, C231.2, C232.2, C233.2, C234.2, C235.2, C236.2, C245.2, C246.2, C247.2, C248.2, C249.2, C250.2, C251.2, C252.2, C253.2, C254.2, C255.2, C256.2, C257.2, C258.2, C259.2, C260.2, C263.2, C264.2, C265.2, C266.2, C267.2, C268.2, C269.2, C270.2, J61.GND, J62.2, J62.4, J62.6, J62.8, J62.10, J62.12, J62.14, J62.16, J62.18, J62.20, J63.GND, J63.GND1, J63.GND3, J64.3, J64.5, J64.9, J67.P$6, J68.2, J68.4, J68.6, J68.8, J68.10, J68.12, J68.14, J68.16, J69.2, J69.4, J69.6, J69.8, J69.10, J69.12, J69.14, J69.16, J70.1, J71.4, J75.1, J75.2, JP13.1, JP13.2, R200.1, R201.1, R202.1, R203.1, R204.1, R205.1, R206.1, R208.1, R212.1, R213.1, R221.1, R222.1, R223.1, S17.1, S18.1, S19.1, S20.1, U25.3, U25.6, U25.7, U25.8, U25.10, U25.29, U25.67, U28.2, U28.3, U28.4, U28.5, U28.6, U28.19, U28.38, U28.40, U29.5, U30.1, U30.3, Y5.2, Y5.4
GND5: C271.2, C272.2, C273.2, C274.2, C275.2, C276.2, C277.2, C278.2, C279.2, C280.2, C281.2, C282.2, C283.2, C284.2, C285.2, C286.2, C287.2, C288.2, C289.2, C290.2, C299.2, C300.2, C301.2, C302.2, C303.2, C304.2, C305.2, C306.2, C307.2, C308.2, C309.2, C310.2, C311.2, C312.2, C313.2, C314.2, C317.2, C318.2, C319.2, C320.2, C321.2, C322.2, C323.2, C324.2, J76.GND, J77.2, J77.4, J77.6, J77.8, J77.10, J77.12, J77.14, J77.16, J77.18, J77.20, J78.GND, J78.GND1, J78.GND3, J79.3, J79.5, J79.9, J82.P$6, J83.2, J83.4, J83.6, J83.8, J83.10, J83.12, J83.14, J83.16, J84.2, J84.4, J84.6, J84.8, J84.10, J84.12, J84.14, J84.16, J85.1, J86.4, J90.1, J90.2, JP16.1, JP16.2, R248.1, R249.1, R250.1, R251.1, R252.1, R253.1, R254.1, R256.1, R260.1, R261.1, R269.1, R270.1, R271.1, S21.1, S22.1, S23.1, S24.1, U31.3, U31.6, U31.7, U31.8, U31.10, U31.29, U31.67, U34.2, U34.3, U34.4, U34.5, U34.6, U34.19, U34.38, U34.40, U35.5, U36.1, U36.3, Y6.2, Y6.4
HSDM: J4.D-, U3.94
HSDM1: J16.D-, U7.94
HSDM2: J31.D-, U13.94
HSDM3: J46.D-, U19.94
HSDM4: J61.D-, U25.94
HSDM5: J76.D-, U31.94
HSDP: J4.D+, U3.95
HSDP1: J16.D+, U7.95
HSDP2: J31.D+, U13.95
HSDP3: J46.D+, U19.95
HSDP4: J61.D+, U25.95
HSDP5: J76.D+, U31.95
I2C_SCK: R15.1, U3.55, U4.46
I2C_SCK1: R74.1, U7.55, U10.46
I2C_SCK2: R122.1, U13.55, U16.46
I2C_SCK3: R170.1, U19.55, U22.46
I2C_SCK4: R218.1, U25.55, U28.46
I2C_SCK5: R266.1, U31.55, U34.46
I2C_SDA: R14.1, U3.64, U4.45
I2C_SDA1: R73.1, U7.64, U10.45
I2C_SDA2: R121.1, U13.64, U16.45
I2C_SDA3: R169.1, U19.64, U22.45
I2C_SDA4: R217.1, U25.64, U28.45
I2C_SDA5: R265.1, U31.64, U34.45
LRCK: R27.1, U3.12
LRCK1: R91.1, U7.12
LRCK2: R139.1, U13.12
LRCK3: R187.1, U19.12
LRCK4: R235.1, U25.12
LRCK5: R283.1, U31.12
LRCK_C: R27.2, U4.1
LRCK_C1: R91.2, U10.1
LRCK_C2: R139.2, U16.1
LRCK_C3: R187.2, U22.1
LRCK_C4: R235.2, U28.1
LRCK_C5: R283.2, U34.1
MCLK: R25.1, U3.15
MCLK1: R89.1, U7.15
MCLK2: R137.1, U13.15
MCLK3: R185.1, U19.15
MCLK4: R233.1, U25.15
MCLK5: R281.1, U31.15
MCLK_C: R25.2, U4.47
MCLK_C1: R89.2, U10.47
MCLK_C2: R137.2, U16.47
MCLK_C3: R185.2, U22.47
MCLK_C4: R233.2, U28.47
MCLK_C5: R281.2, U34.47
MIDI-IN-PIN1: J26.1, R93.1
MIDI-IN-PIN2: D6.A, J26.2, U11.3
MIDI-IN-PIN3: J41.1, R141.1
MIDI-IN-PIN4: J15.1, R45.1
MIDI-IN-PIN5: D3.A, J15.2, U6.3
MIDI-IN-PIN6: D9.A, J41.2, U17.3
MIDI-IN-PIN7: J56.1, R189.1
MIDI-IN-PIN8: D12.A, J56.2, U23.3
MIDI-IN-PIN9: J71.1, R237.1
MIDI-IN-PIN10: D15.A, J71.2, U29.3
MIDI-IN-PIN11: J86.1, R285.1
MIDI-IN-PIN12: D18.A, J86.2, U35.3
MIDI-OUT-PIN1: J26.3, R95.1
MIDI-OUT-PIN2: J26.5, R96.2
MIDI-OUT-PIN3: J41.3, R143.1
MIDI-OUT-PIN4: J15.3, R47.1
MIDI-OUT-PIN5: J15.5, R46.2
MIDI-OUT-PIN6: J41.5, R144.2
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

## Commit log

2015-12-23 Jamie's first draft hardware files.
    [Tapestry.brd, Tapestry.sch]
2015-12-23 Second update from Jamie
    [Tapestry.brd, Tapestry.sch]
2015-12-23 Fixed unconnected nets and missing cap values.
    [Tapestry.brd, Tapestry.sch]
2015-12-23 Changing dashed line to info layer.
    So ERC doesn't think it's a net.
    [Tapestry.sch]
2015-12-24 Replaced generic resistors and capacitors with SparkFun versions.
    [Tapestry.brd, Tapestry.sch]
2016-01-11 First pass over schematic.
    Mostly changing flag style on signals.
    [Tapestry.brd, Tapestry.sch]
2016-01-11 Second pass over schematic
    -Swapped crystal for smaller one.
    -Updated SD card connector with SDIO signal names.
    [Tapestry.brd, Tapestry.sch]
2016-01-11 A little more WIP
    -uSD socket had SDIO naming on pins.
    -pushed parts around PCB.
    [Tapestry.brd, Tapestry.sch]
2016-01-12 Ongoing progress.
    Filled out "layout checklist" in Atmel docs.
    Pushed & pulled components to closer to final proximity.
    [Tapestry.brd, Tapestry.sch]
2016-01-14 Updates all around
    Adjusted LQFP land patterns.
    Switched to LM1117 Vregs.
    Added library to gitignore.
    Ongoing ratsnest work.
    [Tapestry.brd, Tapestry.sch]
2016-01-14 More updates.
    Schematic logos, partitioning & labeling.
    Found a few more absent pullup resistors.
    [Tapestry.brd, Tapestry.sch]
2016-01-18 WIP.
    Checking in so I can traverse project history for a moment.
    [Tapestry.brd, Tapestry.sch]
2016-01-18 Added reset switch & some labeling.
    Still WIP.
    [Tapestry.brd, Tapestry.sch]
2016-01-19 Continuing work.
    Labeling, & sizing mostly complete.
    About ready to route.
    [Tapestry.brd, Tapestry.sch]
2016-01-20 Ready to start routing.
    If I need to fall back, this is the one.
    [Tapestry.brd, Tapestry.sch]
2016-01-21 Routing in progress.
    [Tapestry.brd, Tapestry.sch]
2016-01-22 Routing nearly complete.
    [Tapestry.brd, Tapestry.sch]
2016-01-23 Ready for group review.
    [Tapestry.brd, Tapestry.sch]
2016-01-25 Updates after Monday morning review.
    [Tapestry.brd, Tapestry.sch]
2016-01-26 Adding PROD IDs to components.
    [Tapestry.brd, Tapestry.sch]
2016-01-28 Swapped location of SD socket and reset switches.
    Added some more branding to silkscreen.
    [Tapestry.brd, Tapestry.sch]
2016-02-04 Revising power input.
    Using RG Keen's "ideal diode" for barrel input, avoiding a diode drop on
    the barrel input, so it's prioritized over Vusb if both are plugged in.
    [Tapestry.brd, Tapestry.sch]
2016-02-05 Quick DRC fixes.
    [Tapestry.brd]
2016-02-05 Adding DNS designation to barrel jack.
    [Tapestry.brd, Tapestry.sch]
2016-07-11 Tsunami - very first WIP
    As adapted from Tapestry.
    [tsunami.brd, tsunami.sch]
2016-07-12 Work in progress...
    ...MIDI added, many other small updates.
    [tsunami.brd, tsunami.sch]
2016-07-12 More incremental progress.
    [tsunami.brd, tsunami.sch]
2016-07-14 More work in progress.
    In pretty good shape, but a lot of lingering fit & finish work needed.
    [tsunami.brd, tsunami.sch]
2016-07-18 Proofreading and other touchups.
    [tsunami.brd, tsunami.sch]
2016-07-20 Board updates - nearing completion.
    [tsunami.brd, tsunami.sch]
2016-07-20 Waypoint before renumbering.
    [tsunami.brd, tsunami.sch]
2016-07-20 Lots of little issues handled - did a prelim checklist.
    [tsunami.brd]
2016-07-20 Somehow forgot schem with last commit.
    [tsunami.sch]
2016-07-22 Re-ordering MIDI output pins...
    ...so that they match the pin ordering on a DIN-5.
    [tsunami.brd, tsunami.sch]
2016-07-26 One more ground stitch via
    [tsunami.brd]
2016-07-26 Moving Tapestry board files into a "deprecated" folder.
    [Tapestry.brd, Tapestry.sch]
2016-08-01 Updates from reviews.
    [tsunami.brd, tsunami.sch]
2016-08-02 Some checklist touchups
    JTAG TP's placed on 50 mil grid.
    [tsunami.brd, tsunami.sch]
2016-08-04 Addressing Eric's punch list.
    See issue #2
    [tsunami.brd, tsunami.sch]
2016-11-01 Updates for production.
    Silkscreen touchups.
    -all silk on back is right side up.
    -some size & placement adjustments to labels. Name is larger, some pad
    labels are smaller.
    -JTAG and DEBUG labels removed from both sides of board.
    -Playing is active high, overbar deleted.
    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
    [tsunami.brd, tsunami.sch]
2016-11-07 Post review & production checklist.
    -Centered staking vias on USB.
    -Moved some vias to avoid silk.
    -Text touchups around V reg outputs.
    [tsunami.brd, tsunami.sch]
2016-11-14 Fixing Eric's checklist issues.
    [tsunami.sch]
2016-11-29 Fixing mislabeled MIDI out.
    Pin labels on 2 and 5 were transposed.
    [tsunami.brd]
2016-11-29 Fixing silkscreen labels on panel.
    Transposed 2 and 5 labels on MIDI out port.
    Rolled version to V11 on all files.
    [13240-tsunami-panel.v11.brd, tsunami.brd, tsunami.sch]

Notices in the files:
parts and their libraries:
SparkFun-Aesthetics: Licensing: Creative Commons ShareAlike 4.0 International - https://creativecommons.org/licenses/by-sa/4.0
